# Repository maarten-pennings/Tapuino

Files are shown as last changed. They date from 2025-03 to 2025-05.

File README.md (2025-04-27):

# Tapuino

My take on the famous Tapuino; "The $20 C64 Tape Emulator". 
Below we see the PCB, the assembled PCB, the encased PCB, and again next to the datasette.

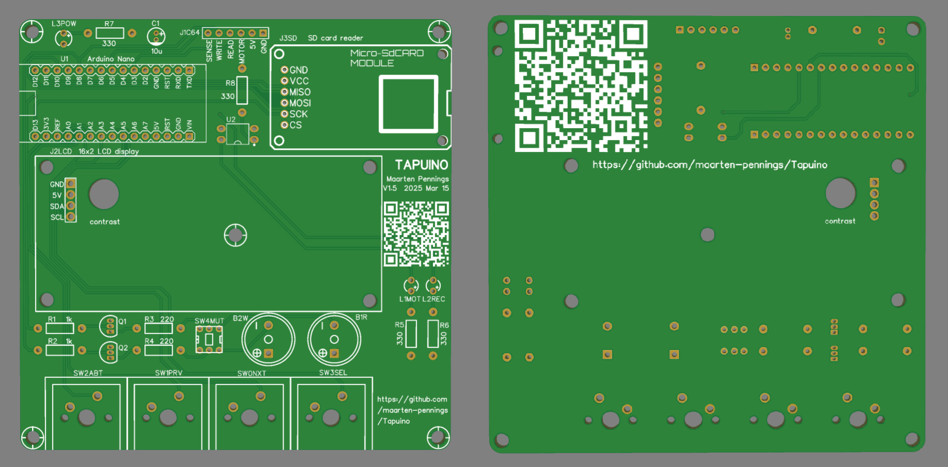
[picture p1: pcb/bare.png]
Tapuino PCB


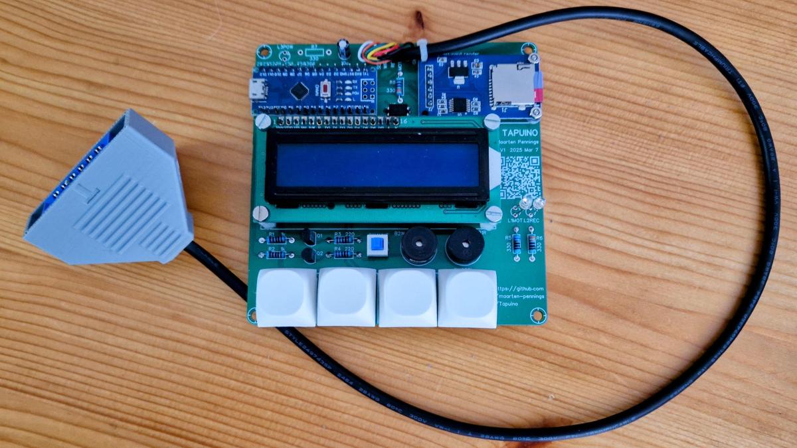
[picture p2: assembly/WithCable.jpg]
Tapuino assembled


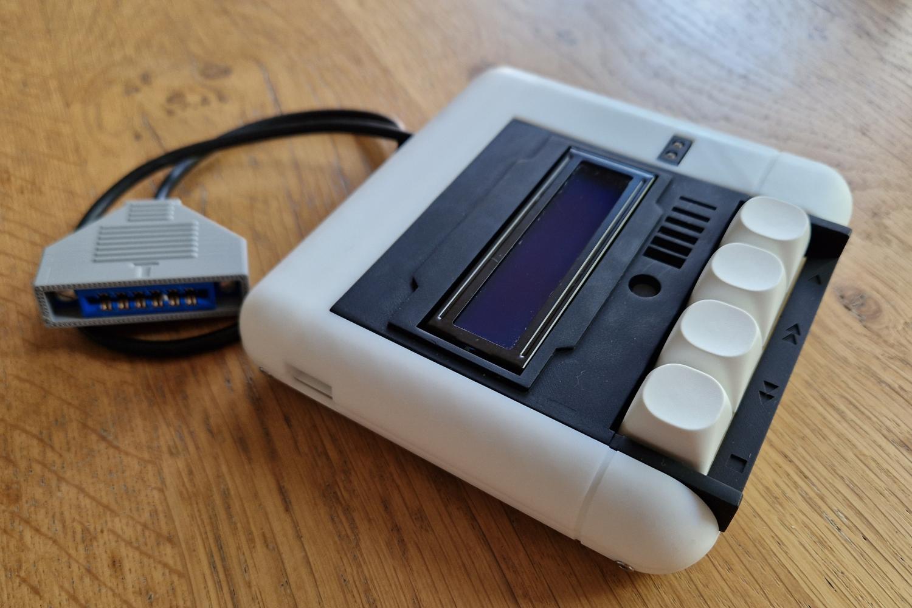
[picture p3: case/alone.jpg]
Tapuino alone


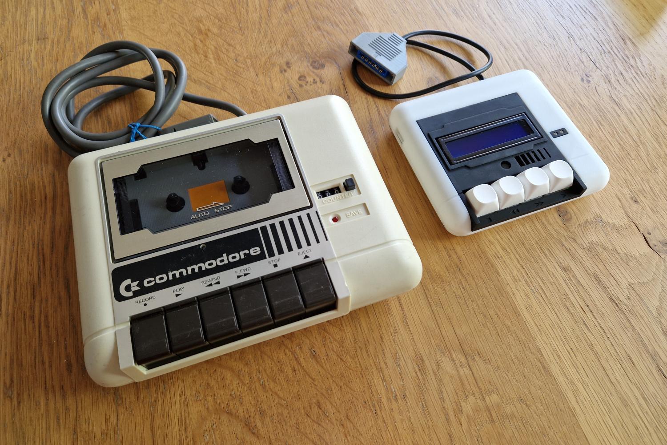
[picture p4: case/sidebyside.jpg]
Tapuino side by side with datasette


## Introduction

This project is a clone of [Tapuino ](https://github.com/sweetlilmre/tapuino) by "sweetlilmre" (Peter Edwards).

In a nutshell: Tapuino is an Arduino Nano, that together with an SD card reader and a 
simple user interface (LCD screen and 4 buttons) implements a sound recorder/player. 
The SD card stores Commodore 64 software in the form of 
[TAP](http://unusedino.de/ec64/technical/formats/tap.html) files; I think of them as 
WAV files; the bleeps encode the software. Tapuino plugs into the (6-pin) cassette 
port of the C64, which also supplies 5V to Tapuino.

The UI on the Tapuino lets you browse through the (directories on the) SD card, selecting a TAP file.
When the user types `LOAD` on the C64, the C64 switches on the MOTOR pin on the cassette 
port, the Arduino sees that and starts playing the TAP file on the READ pin of the 
cassette port. To make the retro experience complete, I added a speaker so that I can hear the bleeps.

It is also possible to type `SAVE` on the C64. In this case the Arduino takes the signal
from the WRITE pin on the cassette port and converts that to a TAP file in a fixed
directory of the SD card. One bummer: the user typically types `SAVE "name"`, but since
the name comes in as bleeps on the WRITE pin, this name is not accessible to the Arduino. 
The user has to enter a name for the file on the SD card, using the Tapuino GUI (slow) or accept 
auto-naming (basically a sequence number). Of course the bleep-encoded file name is still
part of the TAP file, so it is reported back to the C64 upon a `LOAD`.

I do not know if it is a bummer or not, but Tapuino emulates a datasette on the audio level.
This means it also has the speed of the original datasette. Quoting 
[stack exchange](https://retrocomputing.stackexchange.com/questions/16700/did-computer-games-for-commodore-64-really-take-25-minutes-to-load-if-everyth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,minutes%20to%20load%2048%20kilobytes)
"tape data rate is calculated at 55 bytes per second, giving approximately 15 minutes to load 48 kilobytes".
It is however possible to use cassette speed loaders (there is one in this repo as [TAP](tapes) file).

A quick computation: the C64 has 64k of RAM, but most tape games will be smaller than that.
On a 4 GB SD card (Arduino probably handles up to 32 GB) that would mean 4G/64k or 65536 
TAP files. Sounds plenty enough, but be warned the [Tape Archive](https://archive.org/details/Ultimate_Tape_Archive_V4.5) is nearly 20 GB zipped.

## PCB

One problem that I had is that I could not find a complete schematic. 
Peter Edwards' has Fritzing schematics and Vero board drawings, but no real schematics.

For example, the Control 0 and Control 1 lines are still a bit of a mystery.
Also, very hidden, there appears to be a GPIO pin that signals recording as opposed to playing. 

In the end, I did design my own [PCB](pcb).
It's also fun.

Instead of using cheap switches, I decided to go for Cherry MX switches.
Nice and big, looking a bit similar to the big switches on the actual datasette.

## Assembly

I hand assembled the PCB. See result in the [assembly](assembly) directory.
There were some errors in the V1 PCB that had to be patched; see [pcb section](pcb#errors).

## Software

> **Warning** Peter Edwards writes on his GitHub: This project is now in maintenance mode and has been superseded by the Tapuino Next.

And indeed, there are multiple dangling links, for example to Peter's video, and to his blog. 
I did find a [2014 blog](https://sweetlilmre.blogspot.com/2014/07/tapuino-20-c64-tape-emulator.html)

Due to all dangling links, I was afraid the Tapuino [sources](https://github.com/sweetlilmre/tapuino) might disappear. 
I decided to clone the [firmware](firmware), and I made some changes.
The biggest change is character prediction when editing (SAVE) filenames.
I did a bit of statistical counting, see [charcount](charcount).
The first checkin in my repo is the original - without my changes.

## Case

I did design a "sleeve" for the connector, and a 3-part shell for the itself.
The connector was printed at home with a filament printer, the 3-part shell at JLCPCB using SLA printer.
See [case](case).

## Cost

Overall cost is 35 euros. The most expensive part is the casing; without that the Tapuino 
costs just over 15 euros. See [costs](costs).

(end)

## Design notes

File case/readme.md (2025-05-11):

# Tapuino case

This directory contains the 3D printing files.

## Sleeve

I bought a 2x6 pins [PCB connector](https://www.aliexpress.com/item/33015746310.html).
I designed a sleeve for that, that is supposed to look a bit like the original:

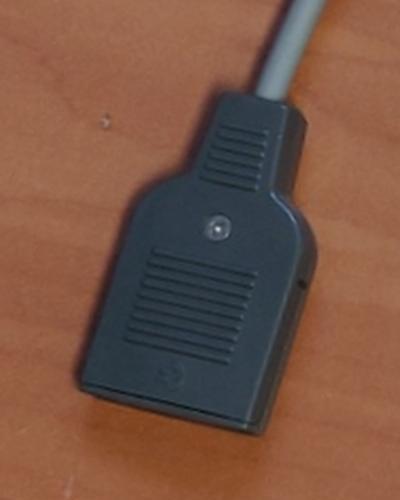
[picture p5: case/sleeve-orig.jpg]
original


This is my version.
The [stl](sleeve-square.stl) is in the repo.

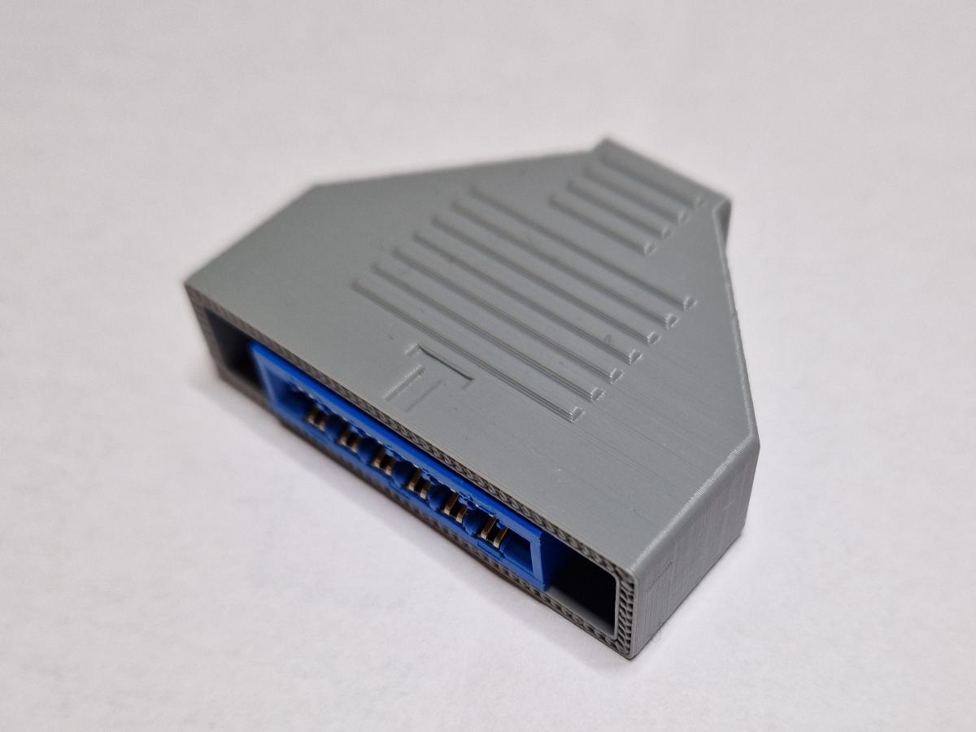
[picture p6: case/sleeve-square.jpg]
mine front
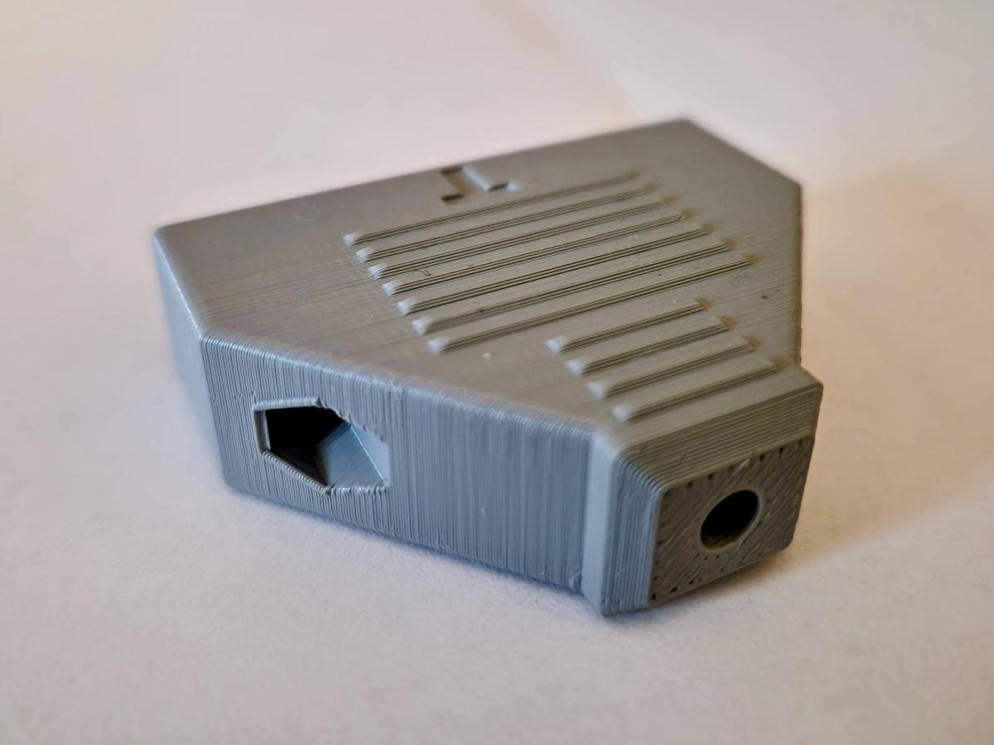
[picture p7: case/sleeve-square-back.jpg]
mine back
  

## Tapuino case V1

I also made a casing for the Tapuino itself.
I wanted it to look like the original datasette.

This is the result of a couple of evenings with Fusion 360.

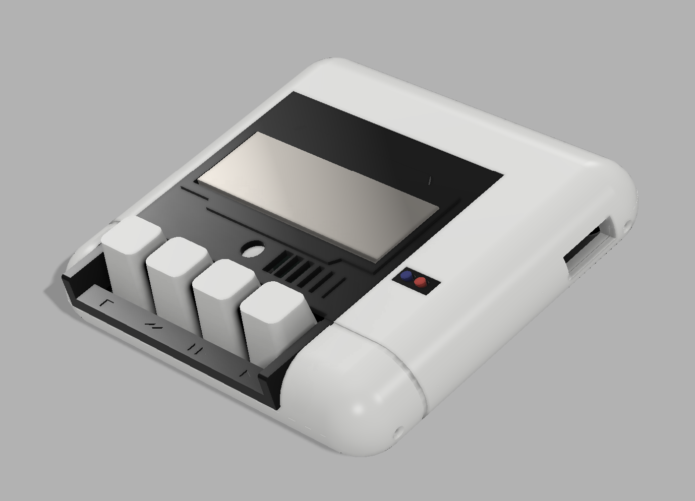
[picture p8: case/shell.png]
shell


It consists of a bottom half ([STL](ShellBot.stl)) and a top half ([STL](ShellTop.stl)) and the top half has a black inlay ([STL](Inlay.stl)).

I made prototypes with my 3D printer, but then ordered at [JLCPCB](https://jlcpcb.com/DMP).
I did go for low(est) cost in material and shipping: €17.30.

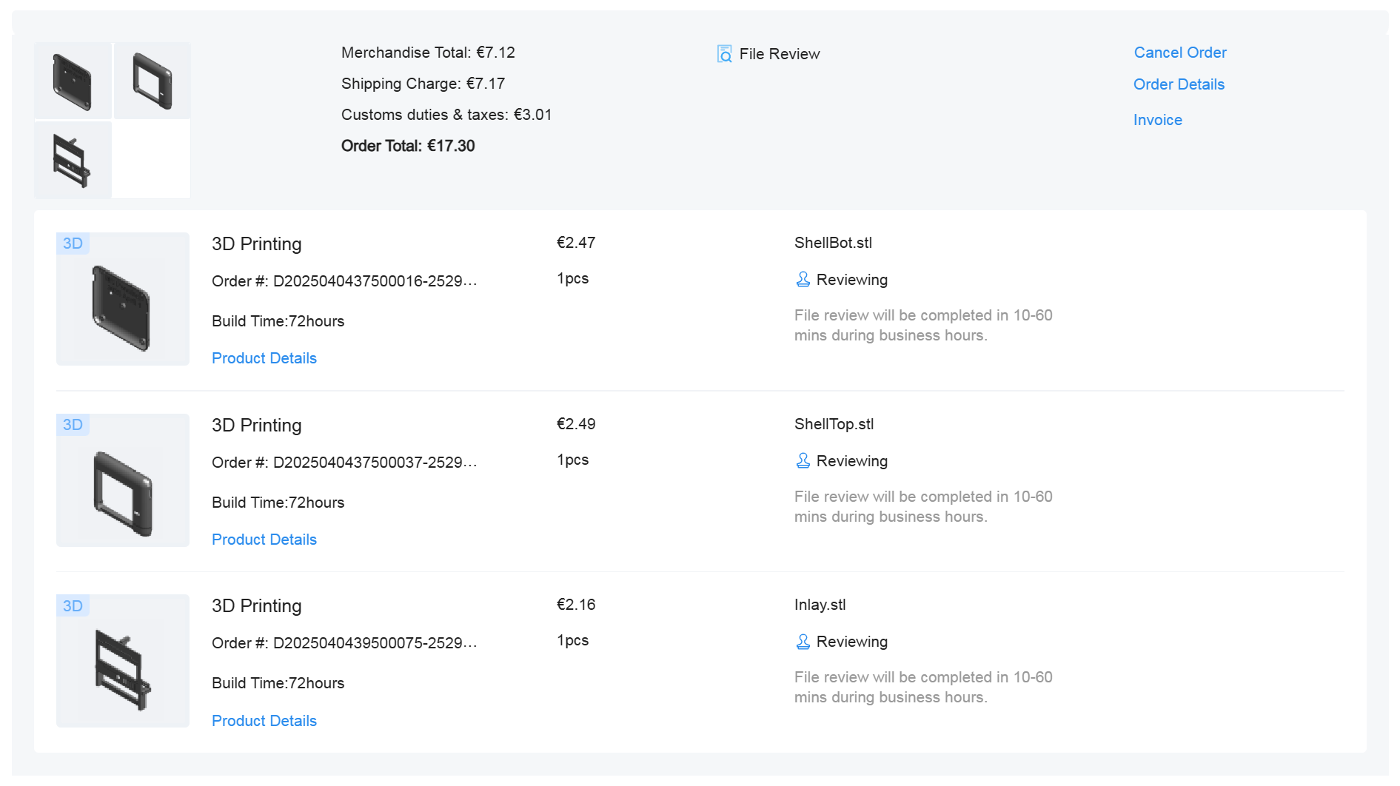
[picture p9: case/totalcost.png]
total cost


Unfortunately, I got a mail from JLCPCB:

> Due to the geometry of this workpiece, there is a high risk of deformation.
> Usually, for flat parts, frame parts, enclosures with no strong ribs inside, and large unoccupied areas parts, long parts and the models could shrink to the center and warping to the diagonal lines and edges.
> Could you please confirm if the risks are acceptable for you?

## Tapuino case V2

I decided to follows JLCPCB's advise and add some ribs; to the bottom half ([STL](ShellBot2.stl)), the top half ([STL](ShellTop2.stl)), and even to the inlay ([STL](Inlay2.stl)),
and to resubmit my order.

Again, I did got for low(est) cost in material and shipping, but more plastic, €1.50 higher cost:

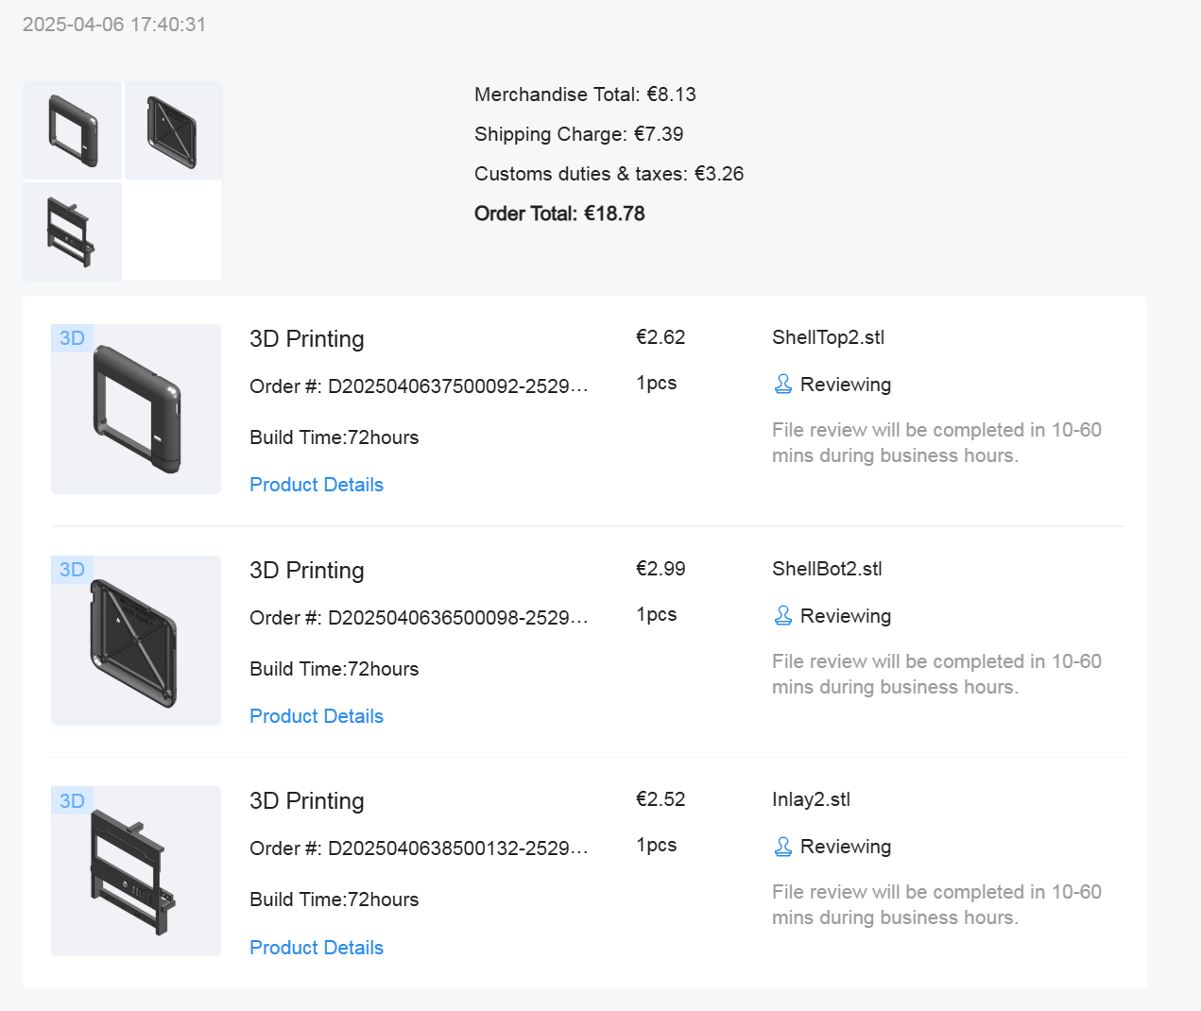
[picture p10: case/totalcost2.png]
total cost v2


## Result V2

Tapuino alone

Tapuino side by side with datasette

## Tapuino case V3

I friend wanted one, so I made some changes to V2.

- LCD gap a bit smaller.
- Lower the (new) ribs in the corner of the bottom, because it prevents the top to go completely down.
- Chamfer the edge of the bottom and top, because I liked the effect of the two halves not completely closing.
- Add an extra rib in the top, because there was a bit of warping in the print I got from JLCPCB.
- I made the chamfer for the heads of the screws that keep the two halves together a bit deeper.
- Now have hex gaps for nuts for the screws that keep the two halves together.
- Added to recessed panels at the top (for the counter and the save LED).
- Added version tags in all three prints.

Here are the (renders of the parts), the bottom half ([STL](ShellBot3.stl)), the top half ([STL](ShellTop3.stl)), and the inlay ([STL](Inlay3.stl)).

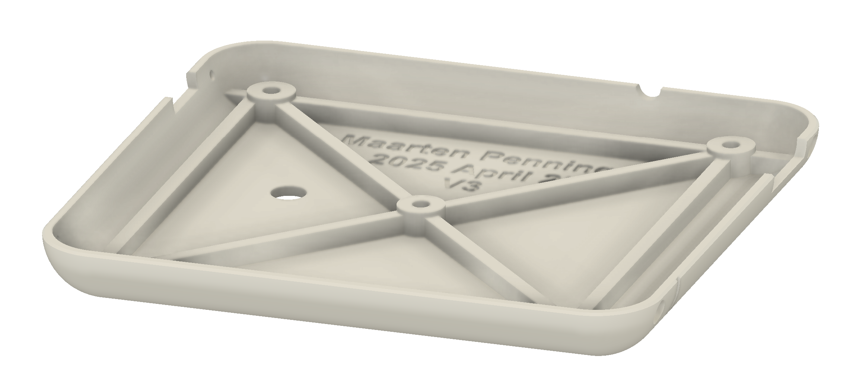
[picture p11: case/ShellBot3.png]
Bottom half V3


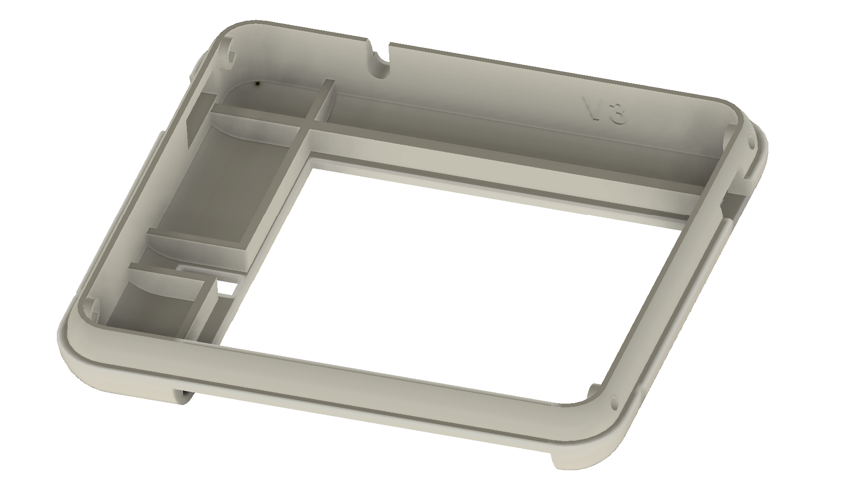
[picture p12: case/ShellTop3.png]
Top half V3


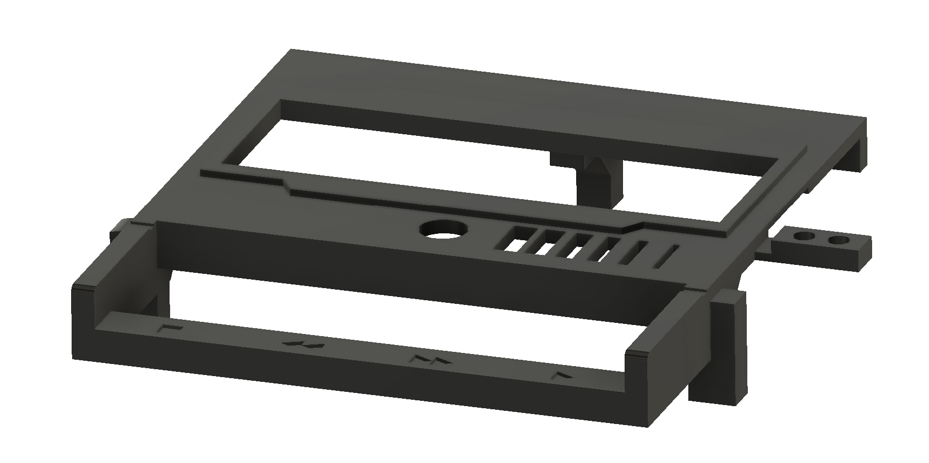
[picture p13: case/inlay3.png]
Inlay V3


This is the render of the assembly.

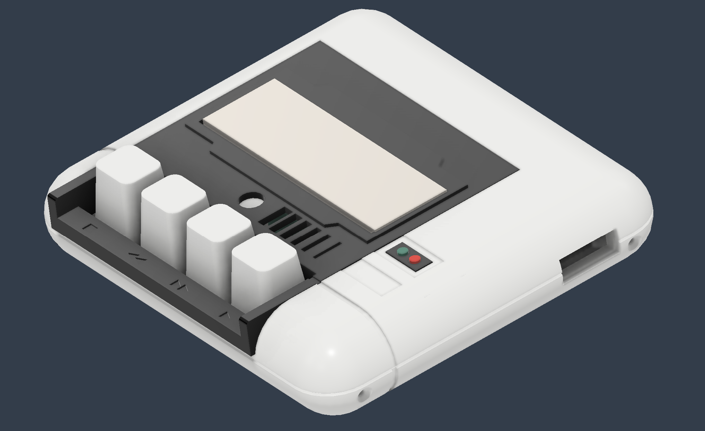
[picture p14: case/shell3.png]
Shell V3


(end)

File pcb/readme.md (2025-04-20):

# Tapuino PCB

In this directory you find my design of the PCB for the Tapuino.

## Schematics

I made the schematics in [EasyEda](https://easyeda.com).
Files are stored in their cloud, but you can also download the [source](Tapuino-sch-v1.5.json).
Not sure how many other tools can process those files.
To be sure, I also exported a [pdf](Tapuino-sch-v1.5.pdf).

Note that I have two sound "channels" one for recording and one for playback.
That is a big overkill, but I didn't want to complicate the schematics
by having two inputs (READ and WRITE pin) to one speaker. It adds a bit of PCB area.
Cost-wise it is not much of a problem, the entire two-channel solution costs less 
than 50 cent (35 for the two buzzers, 6 for the mute button and some cents for the
resistors and transistors). If you don't want sound, you can skip this part of the
schematics.

## Errors

I made a couple of errors in the V1 design that are fixed in the V1.5 design
- SCL/SDA were swapped on the Arduino Nano.
  This was patched by replacing two pins in the pin header of the LCD by wires and crossing those.
- Pins 1/2 and 3/4 were swapped on the optocoupler (U2).
  This was patched by placing the optocoupler upside down (bending all pins 180 degrees).
- Green LED (L1MOT) was too bright.
  Changed R5 from 330 Ω to 680 Ω.

## Layout

Next step is layout, also done in EasyEda. Also here the [source](Tapuino-pcb-v1.5.json) downloaded from the cloud.
And the pdf's, not sure how useful that is, one with [top](Tapuino-pcb-v1.5-top.pdf) view and one with [bottom](Tapuino-pcb-v1.5-bot.pdf) view.

I tried to follow the layout of the original datasette: big buttons at the front;
the tape (LCD) in the center; tape counter (2 LEDs) on the center right; nothing at the back 
except the cable to the C64.

bare

QR code to this repo for on the PCB.

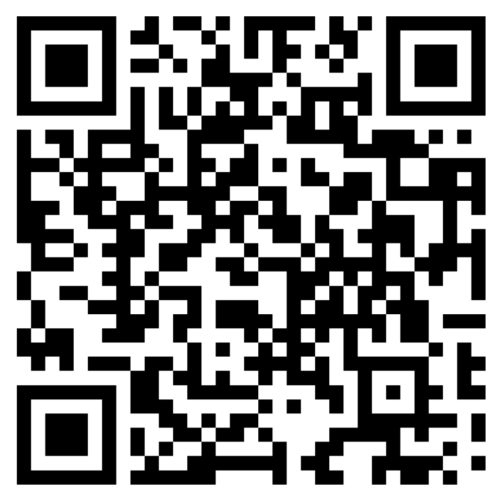
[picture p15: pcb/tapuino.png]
tapuino QR


I made a couple of changes in the v1.5 Layout
- Moved the right-side holes of the SD card PCB a bit to the left
- Moved the contrast hole up.

## Renders

Those fabulous colleague makers using EasyEda, create wonderful "models".
I needed three: for the Arduino Nano, for the SD card reader, and for the LCD screen.
I found all of them, with full details and colors.
So I have pretty good looking renders of my PCB:

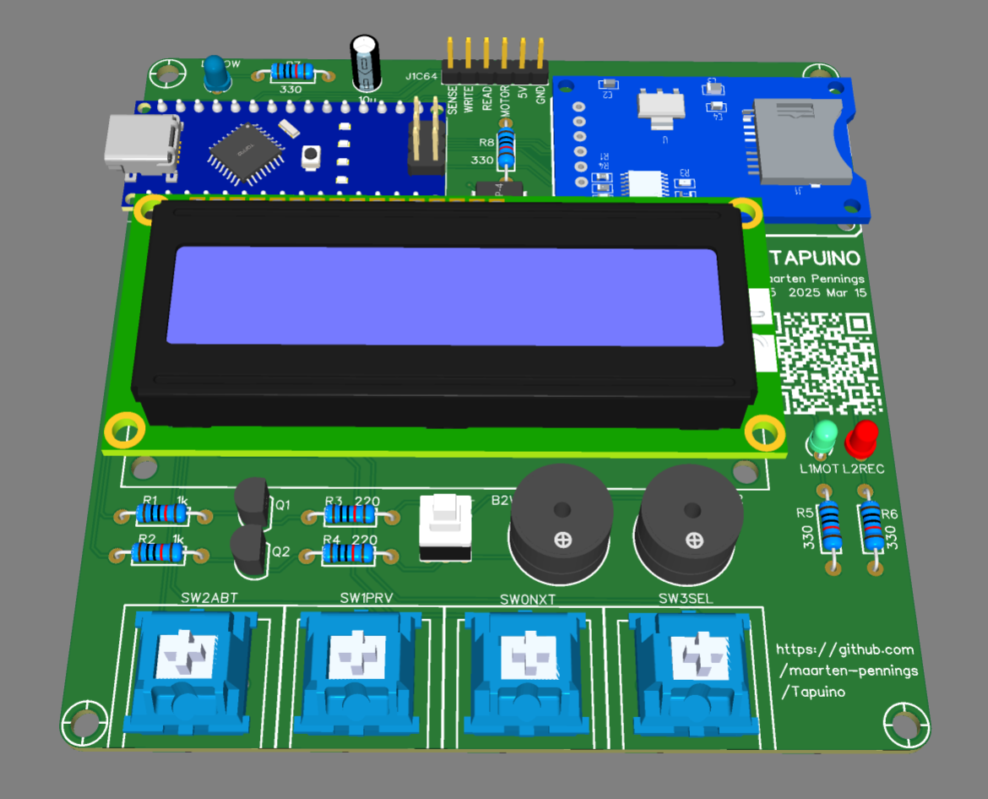
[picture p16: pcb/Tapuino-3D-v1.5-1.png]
render 1


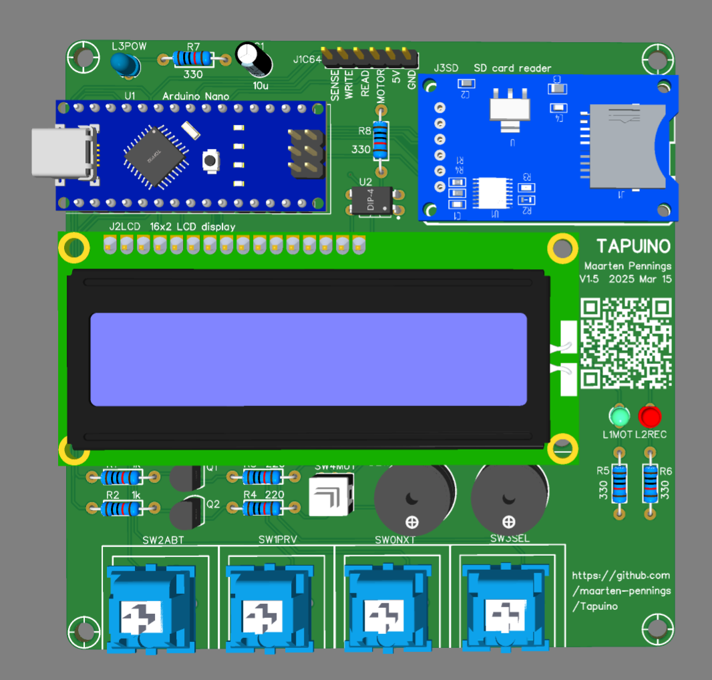
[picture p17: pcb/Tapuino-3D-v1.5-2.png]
render 2


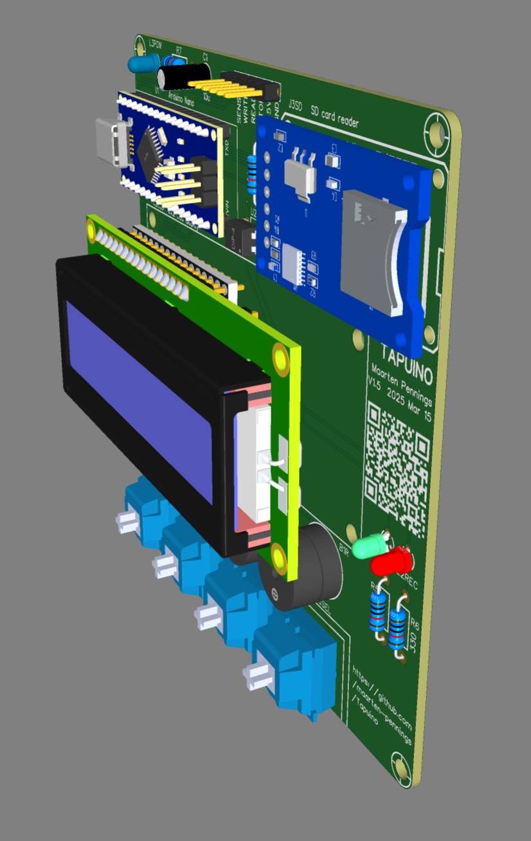
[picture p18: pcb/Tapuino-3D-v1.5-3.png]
render 3


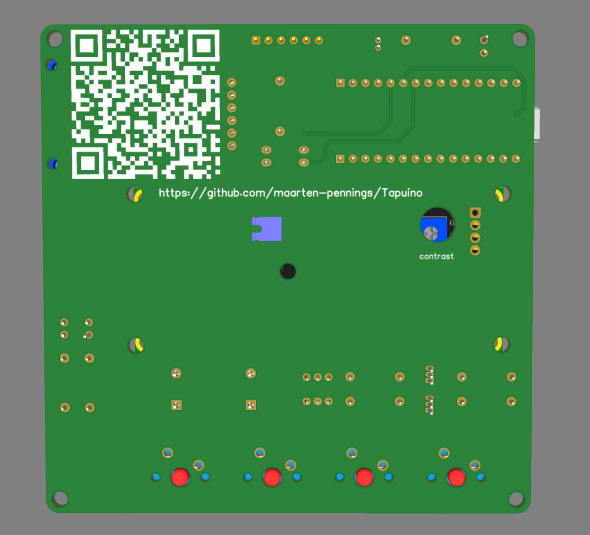
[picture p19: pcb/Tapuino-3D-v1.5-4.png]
render 4


## PCB Manufacturing

The final [gerber](Tapuino-gerber-v1.5.zip) was sent to [JLCPCB](https://jlcpcb.com/DMP).
Manufacturing in 2 days for €1.85 for 5 PCBs. There was 15-day shipping for €1.63, but I opted for
a faster one €6.94.

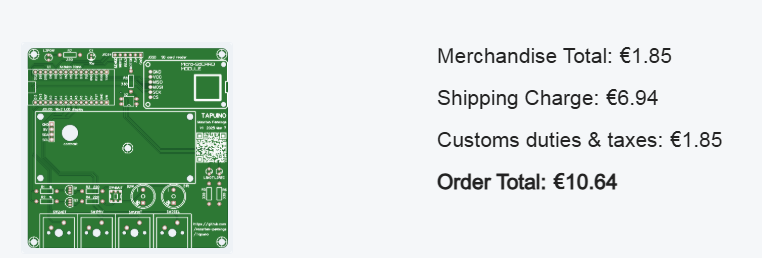
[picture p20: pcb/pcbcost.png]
PCB cost


I ordered on Friday, they arrived at my house (The Netherlands) the next Thursday - four working days.

(end)

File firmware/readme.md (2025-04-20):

# Tapuino firmware

Some notes on the Tapuino firmware.

## My findings

- The UI also has a COMMAND_SELECT_LONG and COMMAND_ABORT_LONG.
  They are especially relevant in manual filename entry (for SAVE)
  
  - Short SELECT means start editing next character.
  - Long SELECT means select character, stop entering characters, start recording the file.
  - Short ABORT means go back to editing previous character.
  - Long ABORT means stop entering file name.

- Lowercase `m` on the LCD means waiting for motor power by C64.
  Uppercase `M` means C64 powers the motor.
  
- The main menu also has "options" configuration.

## My changes

- I changed all sources to have uniform line endings.

- I added my configuration in [config-user.h](config-user.h).

- Suppressed a [warning ](https://github.com/maarten-pennings/Tapuino/blob/main/firmware/tapuino/ccsbcs_avr.c#L9).

- Fixed some typos (eg [Ether](https://github.com/maarten-pennings/Tapuino/blob/main/firmware/tapuino/config.h#L9)).

- In the "file browser" shown with "play" I filtered out also _hidden_ and _system_ files.
  See [source](https://github.com/maarten-pennings/Tapuino/blob/main/firmware/tapuino/fileutils.c#L8).
  The "system" was needed because windows creates a some funny system directory each time I plug in the SD card in my system.
  I added  "hidden" because this allows me to add some files (documentation, images) that I do not want to pop up in the Tapuino browser.

- Replaced hard-coded sizes with expression (eg [`sizeof(ppitems)/sizeof(ppitems[0])`](https://github.com/maarten-pennings/Tapuino/blob/main/firmware/tapuino/menu.c#L272)
  and line [373](https://github.com/maarten-pennings/Tapuino/blob/main/firmware/tapuino/menu.c#L373), and 
  [463](https://github.com/maarten-pennings/Tapuino/blob/main/firmware/tapuino/menu.c#L463)).

- I was confused by `TAPE_READ_LOW` which sometimes referred to a LED. Changed that to [signal](https://github.com/maarten-pennings/Tapuino/blob/main/firmware/tapuino/tapuino.c#L453).

- I bumped the version from 2.10.0 to 2.11.0.

- Added character prediction to manual [file name entry](https://github.com/maarten-pennings/Tapuino/blob/main/firmware/tapuino/menu.c#L178).
  See also [next char](https://github.com/maarten-pennings/Tapuino/blob/main/firmware/tapuino/memstrings-neutral.c#L7) definition.
  
- I bumped the version from 2.11.0 to 2.12.0.

- Changed startup message from `INIT... V: 2.12.0` to `Tapuino 2.12.0`

- I bumped the version from 2.11.0 to 2.13.0.

## Uploading

Upload failed at first. Forgot my Nano has an "old" bootloader.

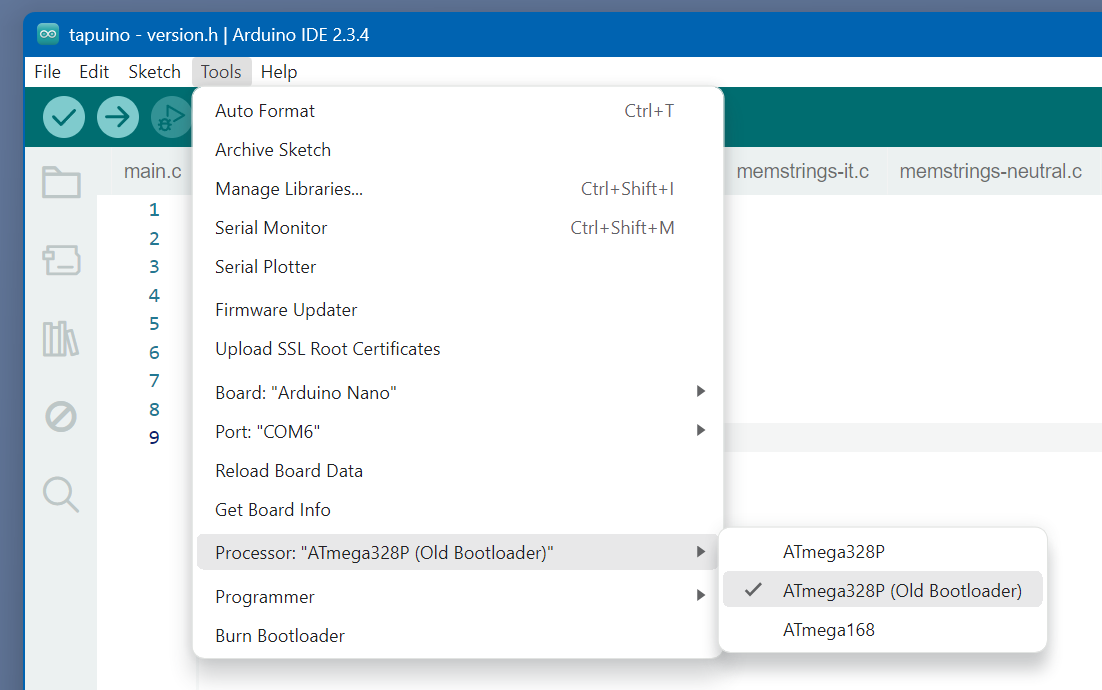
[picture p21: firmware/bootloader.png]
bootloader


Memory usage is relatively low

```
Sketch uses 26868 bytes (87%) of program storage space. Maximum is 30720 bytes.
Global variables use 1608 bytes (78%) of dynamic memory, leaving 440 bytes for local variables. Maximum is 2048 bytes.
```

In 2.12/13

```
Sketch uses 26990 bytes (87%) of program storage space. Maximum is 30720 bytes.
Global variables use 1608 bytes (78%) of dynamic memory, leaving 440 bytes for local variables. Maximum is 2048 bytes.
```

(end)

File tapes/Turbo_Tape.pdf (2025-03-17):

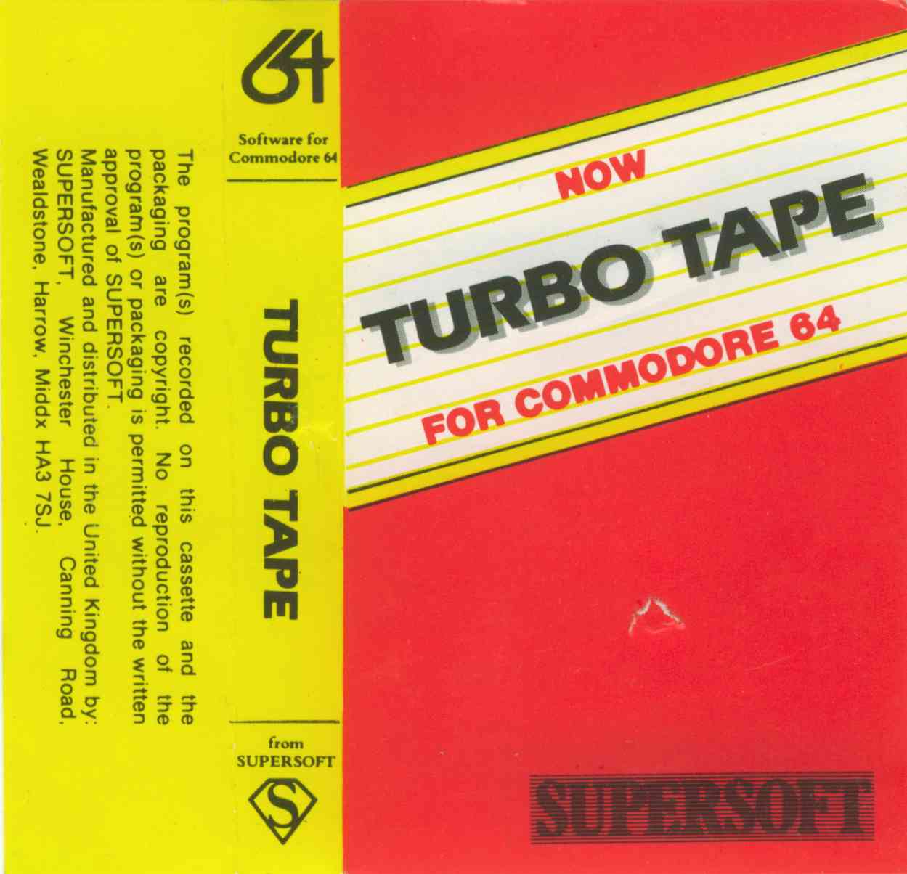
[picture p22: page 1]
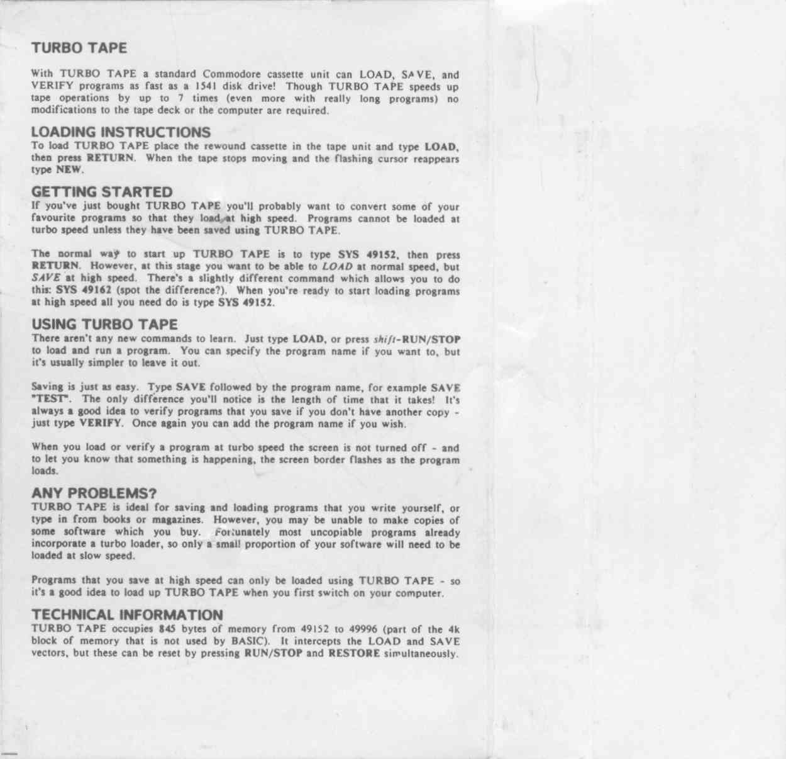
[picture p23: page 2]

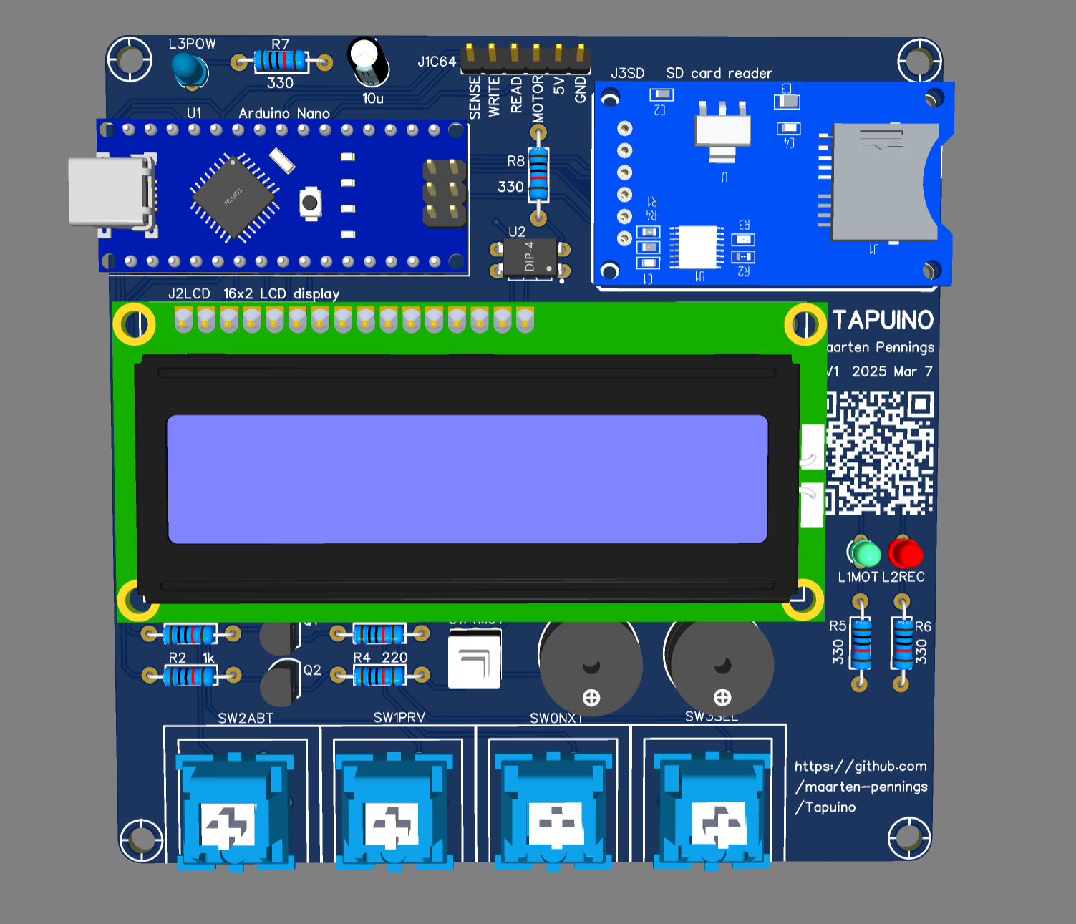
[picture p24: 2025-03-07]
pcb/Tapuino-3D-v1-2.png

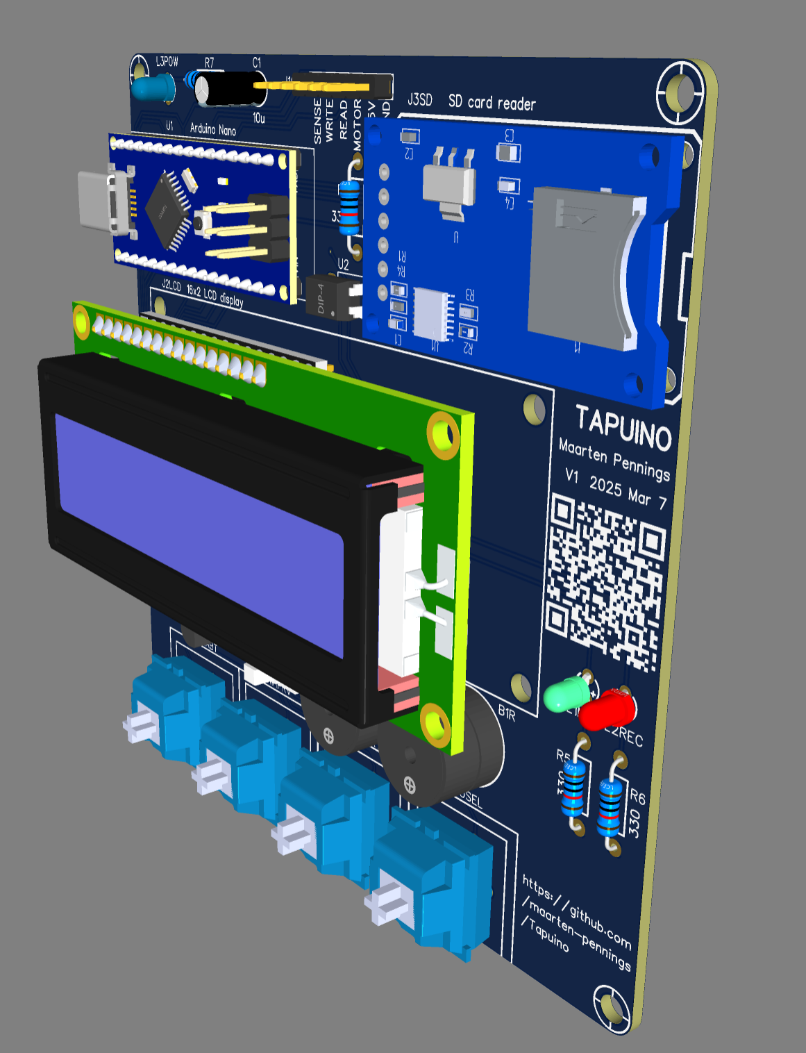
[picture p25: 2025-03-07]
pcb/Tapuino-3D-v1-3.png

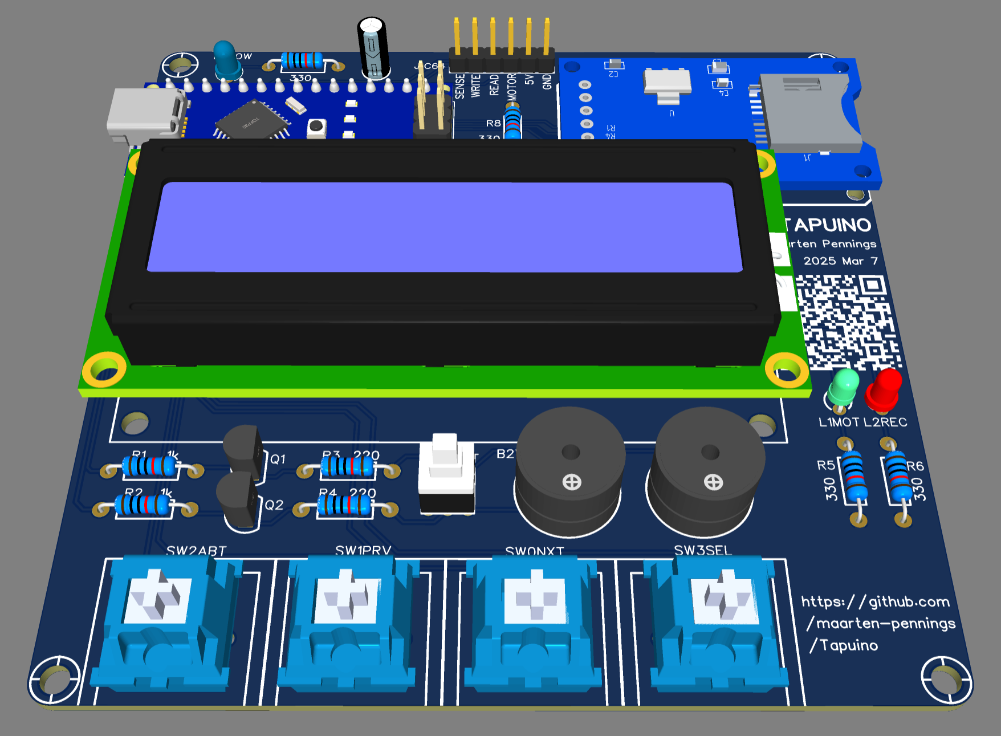
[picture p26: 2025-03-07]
pcb/Tapuino-3D-v1-1.png

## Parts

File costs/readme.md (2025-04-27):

# Tapuino costs

This file gives an indication of the costs for making a Tapuino.

## Components

- [Arduino Nano](https://www.aliexpress.com/item/4000310677263.html)
  with micro USB (maybe I should have gotten USB C). 1 for €2.94.

- [Edge connector](https://www.aliexpress.com/item/33015746310.html);
  3 for €1.96.

- [16x2 LCD with I2C adapter](https://www.aliexpress.com/item/1005006964073869.html).
  I took the blue one. 1 for €2.62.

- [SD card reader module](https://www.aliexpress.com/item/1005006457603056.html)
  with 3v3 LDO and level shifters. 1 for €1.08.

- [BC547 transistor](https://www.aliexpress.com/item/1005007339082012.html);
  100 for €1.33.

- [LEDs in blue, green, red](https://www.aliexpress.com/item/1005005708510866.html);
  100 for €1.83.
  
- [Passive Buzzer](https://www.aliexpress.com/item/1005007548587680.html)
  ("passive" means it is like a speaker driven by AC, "active" means
  it contains an oscillator driven at DC and it makes one fixed beep tone).
  10 pieces for €1.76.

- [Clicky blue Cherry MX switches](https://www.aliexpress.com/item/1005007052759423.html)
  30 for €3.63. I hope they are 1 unit wide (0.75 inch or 19.05mm).

- [Key caps](https://www.aliexpress.com/item/1005006477890497.html)
  for the Cherry MX switches. 30 pieces for €10.94.

- [Mute button](https://www.aliexpress.com/item/32699676258.html).
  I used the "self locking" (blue) with 2mm pitch.
  It is a double pole, double throw; 40 switches for €2.49.

- [Resistors](https://www.aliexpress.com/item/1005008240285872.html);
  1280 for €7.09.

- [Opto coupler](https://www.aliexpress.com/item/1005006281381268.html);
  20 for €1.09.

- [capacitors](https://www.aliexpress.com/item/1005007426523574.html);
  120 for €2.66.

## Cost

The table below lists the cost.
Be aware that this table is overly positive; it does not include shipping
for the bulk goods and it assumes the overshoot parts are useful for another project.

| Name | Designator | Quantity  |  Price  |
|:---|:---|:---:|---:|
| Arduino nano | U1 | 1 | €  2.94 |
| Edge connector to C64 | J1C64 | 1 | €  0.65 |
| LCD module | J2LCD | 1 | €  2.62 |
| Micro SD Card-module  | J3SD | 1 | €  1.08 |
| BC547B | Q1,Q2 | 2  [0] | €  0.03 |
| LED 3mm | L1MOT, L2REC, L3POW | 3  [0] | €  0.05 |
| Passive buzzer | B1R,B2W | 2  [0] | €  0.35 |
| Cherry MX keys | SW0NXT,SW1PRV,SW2ABT,SW3SEL | 4 | €  0.48 |
| Key caps | SW0NXT,SW1PRV,SW2ABT,SW3SEL | 4  [0] | €  1.46 |
| Switch DPDT | SW4MUT | 1  [0] | €  0.06 |
| Resistor 330Ω | R5,R6,R7,R8 | 4  [1] | €  0.02 |
| Opto coupler PC817C | U2 | 1 | €  0.05 |
| Resistor 1kΩ | R2,R1 | 2  [0] | €  0.01 |
| Resistor 220Ω | R3,R4 | 2  [0] | €  0.01 |
| 10u | C1 | 1 | €  0.02 |
| | | | |
| PCB | (5 piecs with shipping) | 1 | €  2.13 |
| Casing 3 parts | (with shipping) | 1 | € 18.78 |
| | | | |
| SD card | | 1 | €  2.28 |
| | | | |
| | | | € 33.02 |

The casing is by far the most expensive part, which you don't need. 
If you want to reduce more, you could consider removing all three LEDs, 
the buzzer and its driver circuit. But this is all cents range.
The biggest saving is replacing the cherry switches and caps 
with cheaper switches.
The optional PCB cost reductions are tagged with [ ] in the cost overview.

(end)

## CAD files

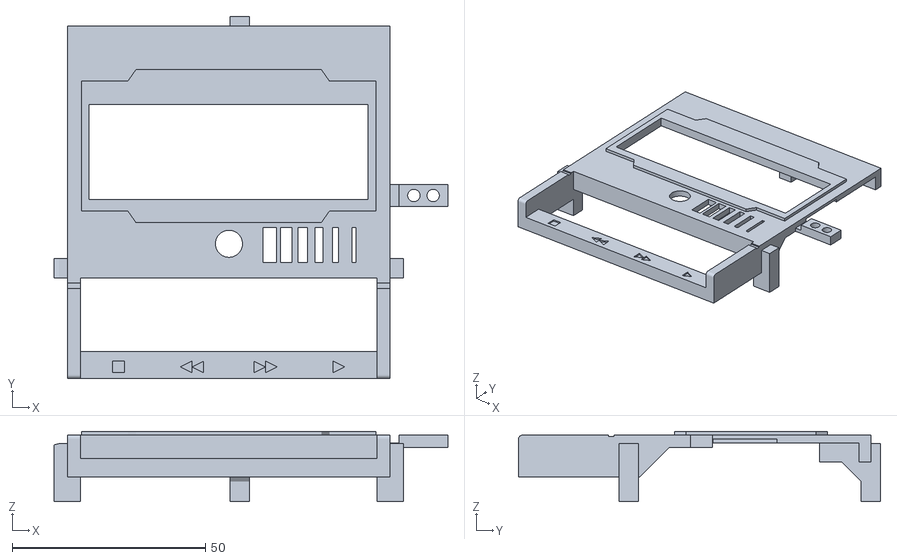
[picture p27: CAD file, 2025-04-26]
case/Inlay3.stl
101.8 x 93.6 x 18.2

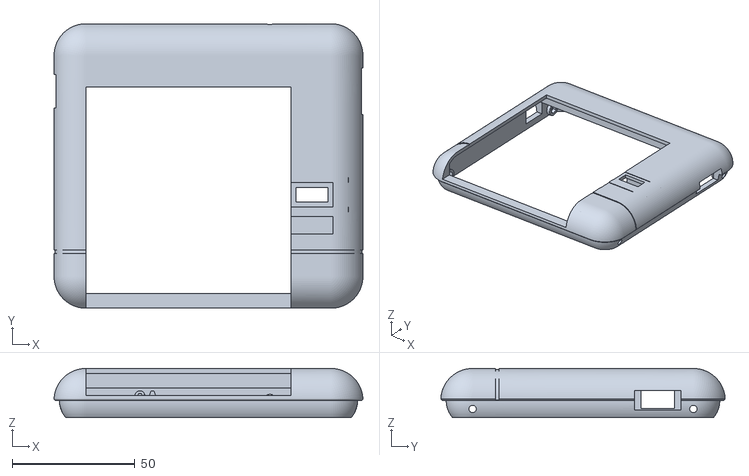
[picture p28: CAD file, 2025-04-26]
case/ShellTop3.stl
126.0 x 116.0 x 20.0

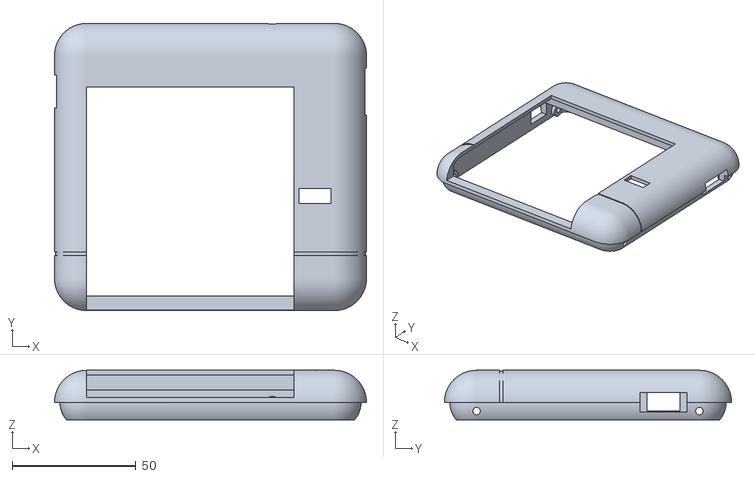
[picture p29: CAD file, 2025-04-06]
case/ShellTop2.stl
126.0 x 116.0 x 20.0

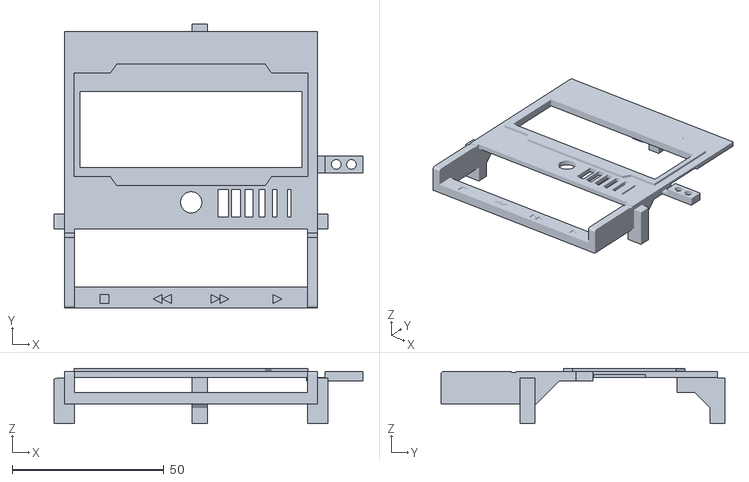
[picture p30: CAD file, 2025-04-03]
case/Inlay.stl
101.8 x 93.6 x 18.2

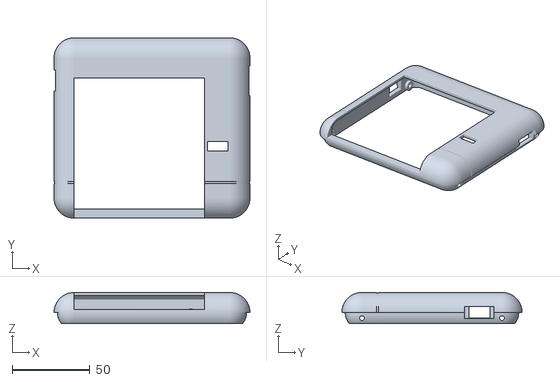
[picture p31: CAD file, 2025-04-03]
case/ShellTop.stl
126.0 x 116.0 x 20.0

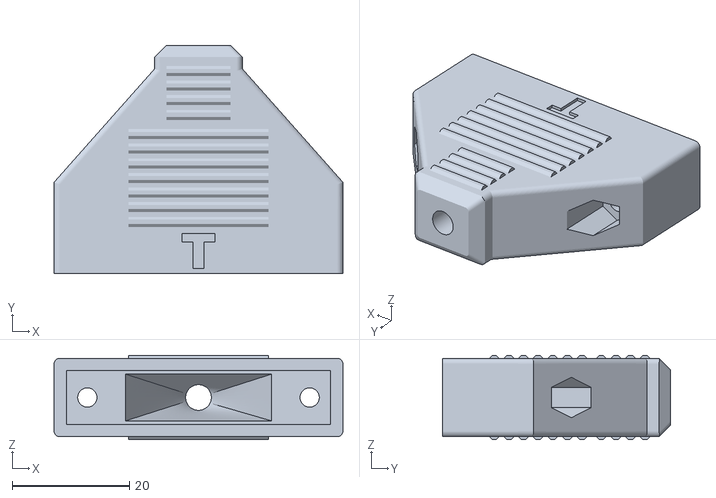
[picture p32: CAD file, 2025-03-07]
case/sleeve-square.stl
49.4 x 39.0 x 14.4

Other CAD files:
case/Inlay2.stl

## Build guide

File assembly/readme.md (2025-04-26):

# Assembly

In this directory you find my assembly results.

## Bare PCB

The 5 PCBs arrived after only 4 working days.
I ordered them without assembly, so that was my next step.

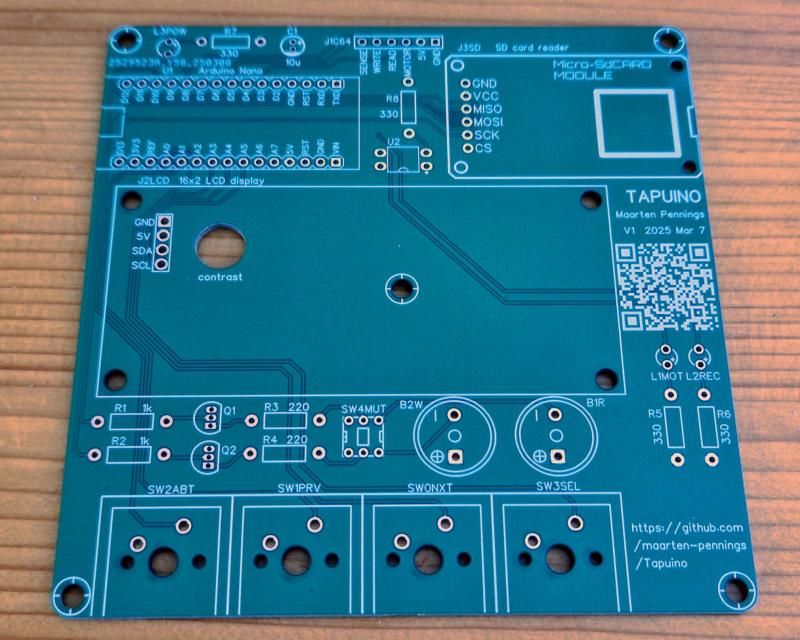
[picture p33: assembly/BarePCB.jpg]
Bare PCB


There are some [errors](https://github.com/maarten-pennings/Tapuino/tree/main/pcb#errors) in the V1.5 PCB.

These are the steps I followed for my second assembly.

- First, I flashed the Arduino Nano with a "blinky plus println".
  I'm glad I did this. The Nano did start, but it did not enumerate over USB.
  I discovered a capacitor was knocked off the board. When I mounted one back, all was fine.
  
  I flashed the Arduino Nano with the Tapuino [firmware](https://github.com/maarten-pennings/Tapuino/tree/main/firmware/tapuino).
  Unfortunately, it is hard to test on the bare board; I connected the LCD with clipwires 
  and saw `Init failed!`, which make sense because there is no SD board connected yet.

- I removed the power LED from the Nano.
  You do not need to do this, but the white casing is not opaque enough to block it, so I don't like it.

  I soldered the Nano, on pin headers, with the long side of the pins up.
  Otherwise they stick out at the bottom where there is not enough room, so a lot of clipping would then be needed.

- I soldered the LCD with SDA and SCL as wires instead of pin headers.
  This is needed because due to **PCB error**, they need to be crossed.

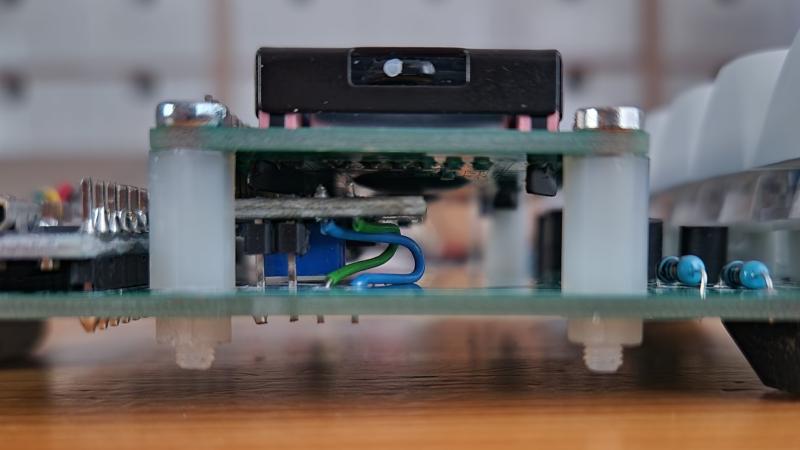
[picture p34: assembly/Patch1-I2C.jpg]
I2C swap
  
  
  I forgot, but I should have removed the red LED.
  Then I secured the LCD with standoffs 10mm. 
  
- Next I did the SD module. I first removed the existing pin header because I want the SD card slot at the top.
  Next I soldered the SD module on the PCB and secured it with on bolt, thick washer/spacer and a nut.

  Powering up the board now (with a working SD card inserted), no longer causes an error message on the LCD.
  
- The sound components needed to be placed before the keys (room wise),
  so the two buzzers, the mute button, four resistors and two transistors were placed next.
  
- I soldered the four cherry switches.

  Powering up the board in this stage, allow us to navigate the menu with the buttons.
  
- To test the sound, I needed to add the optocoupler, because via the optocoupler the "load" signal comes in.
  Here I needed to work around the second **PCB error**.
  The anodes and cathodes of the optocoupler are swapped; "fortunately" I did that twice, for the emitter as well as the detector.
  The second patch was to turn the optocoupler on its back, bending all 4 legs 180°.

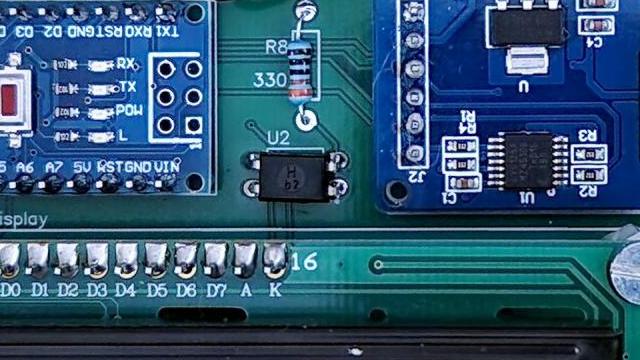
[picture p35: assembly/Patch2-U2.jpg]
U2 swap
  
  
  The pin 1 was is no longer at the lower right (where the marking dot is) but at the upper right (to wards R8).

  When you now power the board, and select a file to play, the Nano is waiting for 5V on MOTOR.
  By short circuiting the MOTOR and 5V on J1C64 playback should start: animation on the LCD and
  sound (remember to toggle the mute button - SW4MUT - if you don't hear beeps).

- Finally, I mounted the 10u cap, and the green (L1MOT) and red (L2REC) LEDs with their resistor (R5, R6).
  I did not mount the power LED (L3POW) with its resistor (R7).
  It is not really a **PCB error**, but I replaced R5 330Ω with 1000Ω, because it would be too bright.
  
  I repeated the play test from the previous step, now also the green LED switches on.

## With cable

The PCB seemed to work fine on USB, faking motor on by short circuiting the MOTOR and 5V on J1C64.

Next step was to add the cable with my own printed connector sleeve.

With cable

## Assembly completed

In the following photos you see the Tapuino in action.

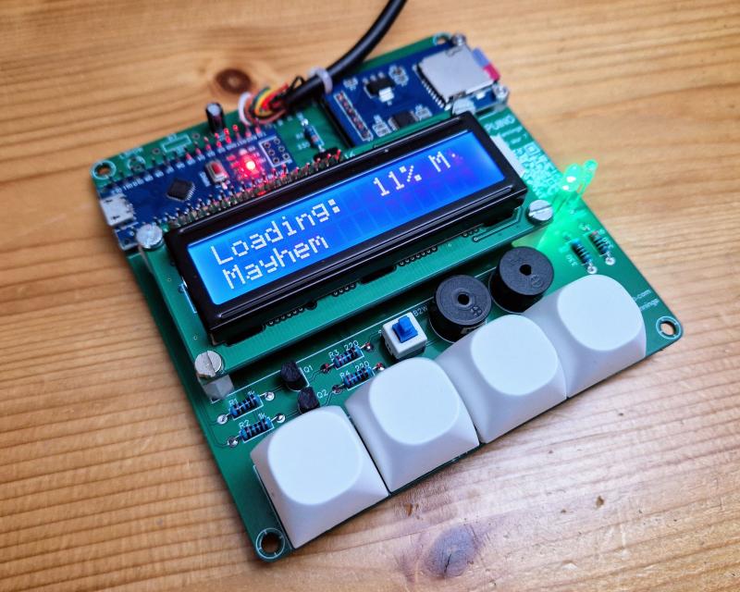
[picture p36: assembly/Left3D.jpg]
Left


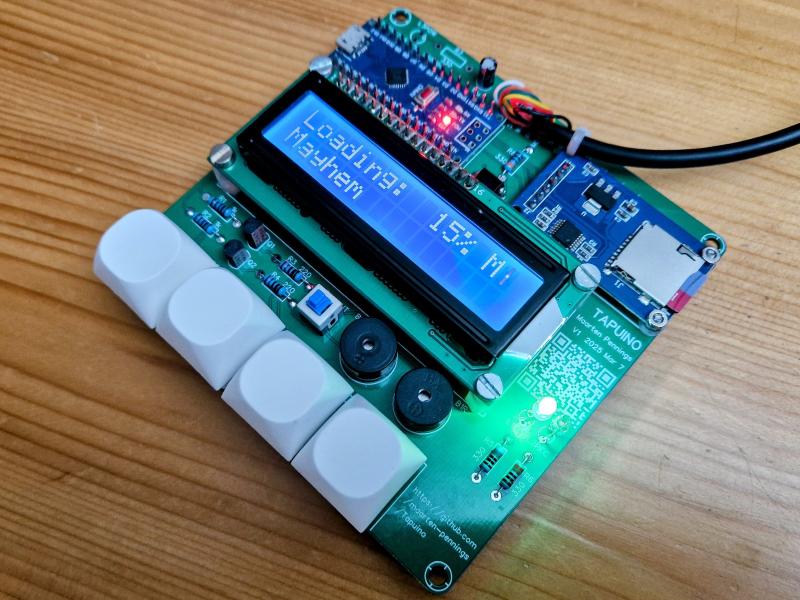
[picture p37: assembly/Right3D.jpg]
Right


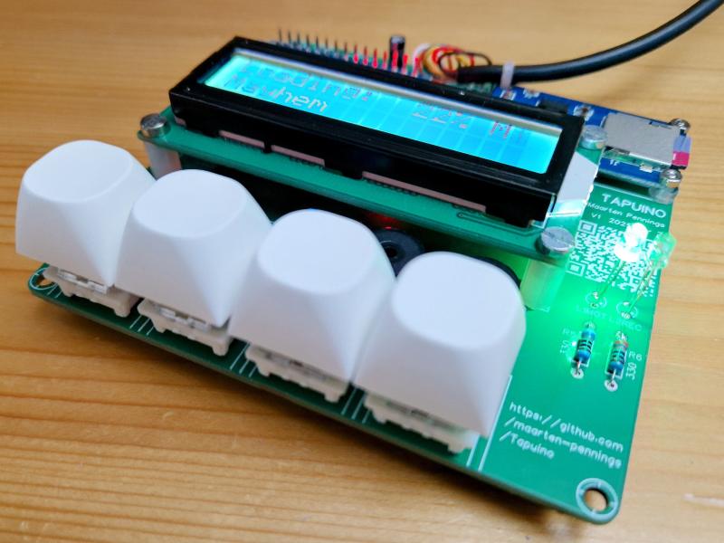
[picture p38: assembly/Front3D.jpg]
Front


(end)

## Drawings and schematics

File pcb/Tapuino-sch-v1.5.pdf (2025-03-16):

## LOAD and SAVE monitor

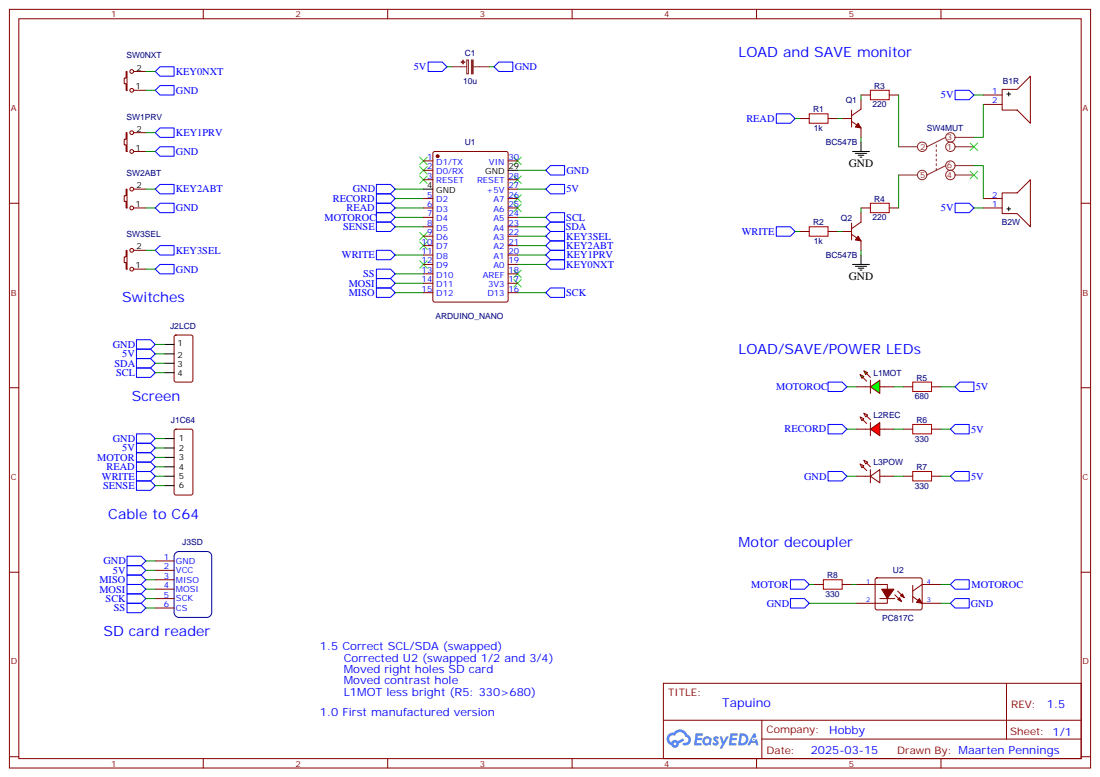
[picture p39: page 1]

LOAD/SAVE/POWER LEDs

1.5 Correct SCL/SDA (swapped)
Corrected U2 (swapped 1/2 and 3/4)
Moved right holes SD card
Moved contrast hole
L1MOT less bright (R5: 330>680)
1.0 First manufactured version

Drawn By: Maarten Pennings

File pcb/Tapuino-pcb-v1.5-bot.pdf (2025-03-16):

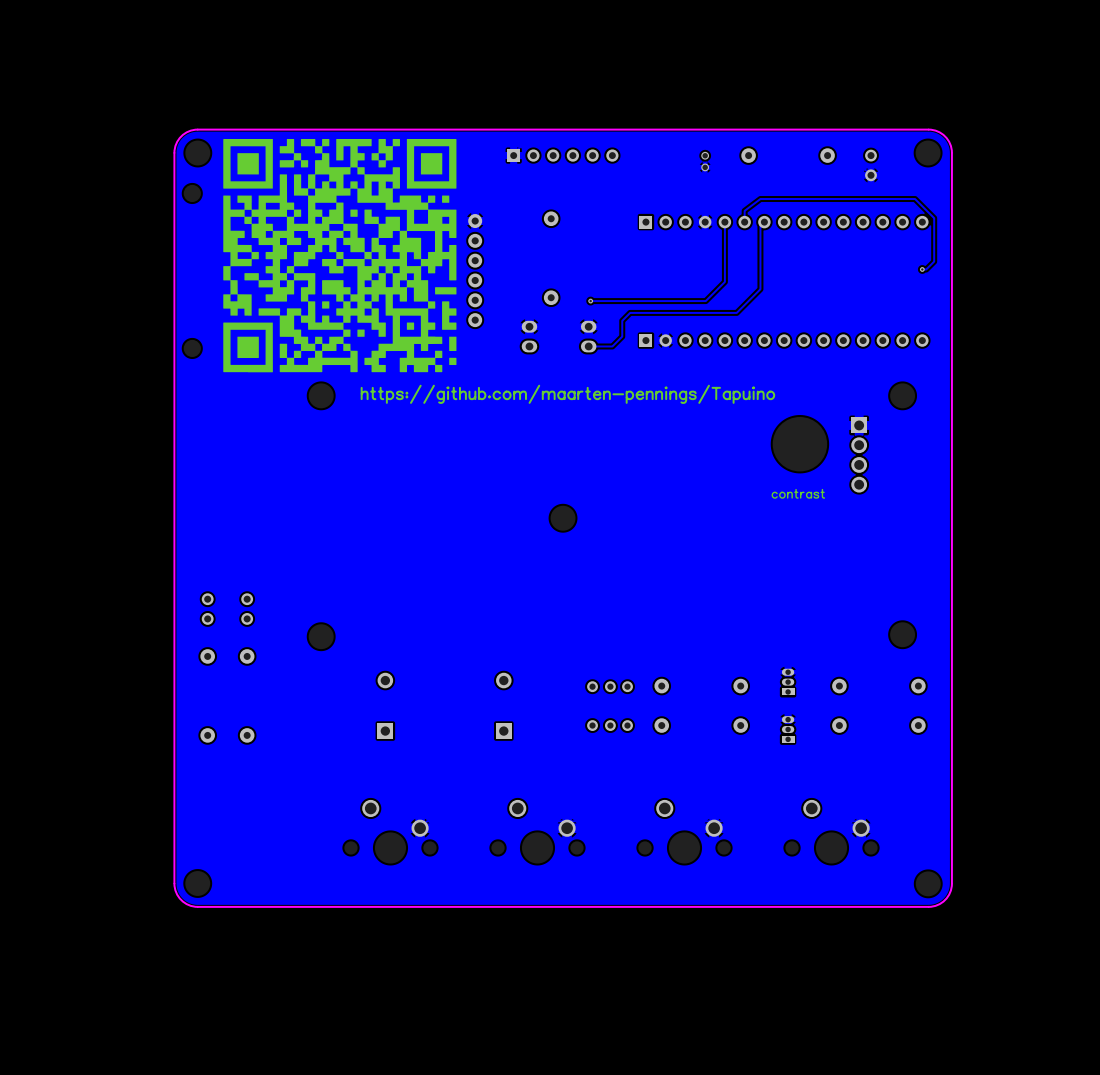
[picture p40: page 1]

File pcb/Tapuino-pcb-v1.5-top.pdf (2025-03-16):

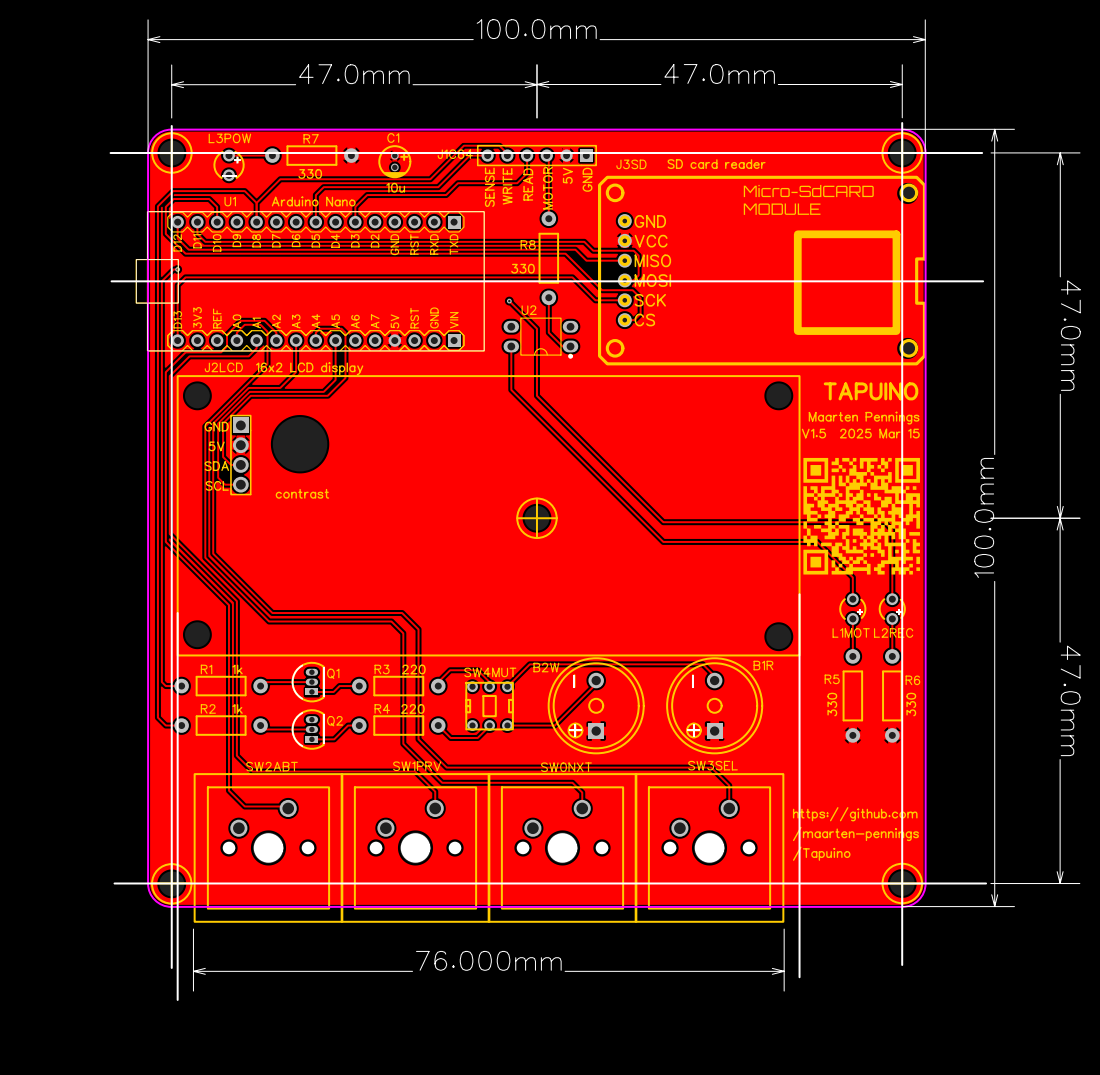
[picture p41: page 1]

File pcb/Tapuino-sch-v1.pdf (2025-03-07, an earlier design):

## LOAD and SAVE monitor

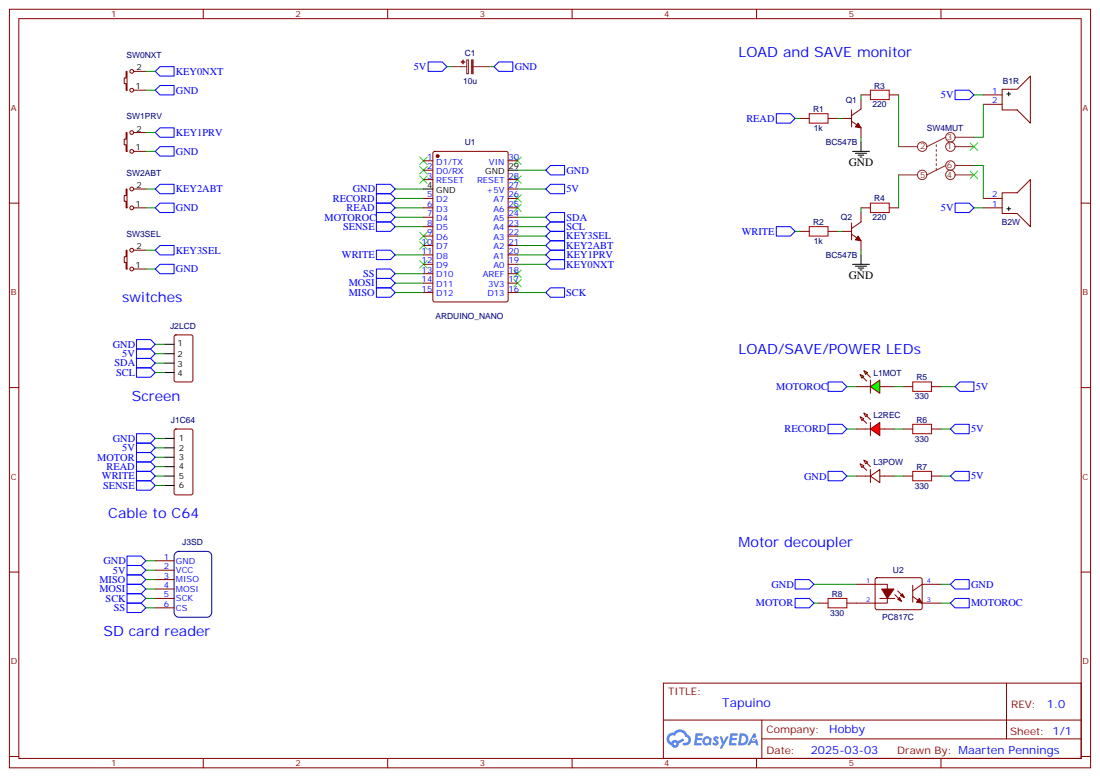
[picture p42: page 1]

LOAD/SAVE/POWER LEDs

Drawn By: Maarten Pennings

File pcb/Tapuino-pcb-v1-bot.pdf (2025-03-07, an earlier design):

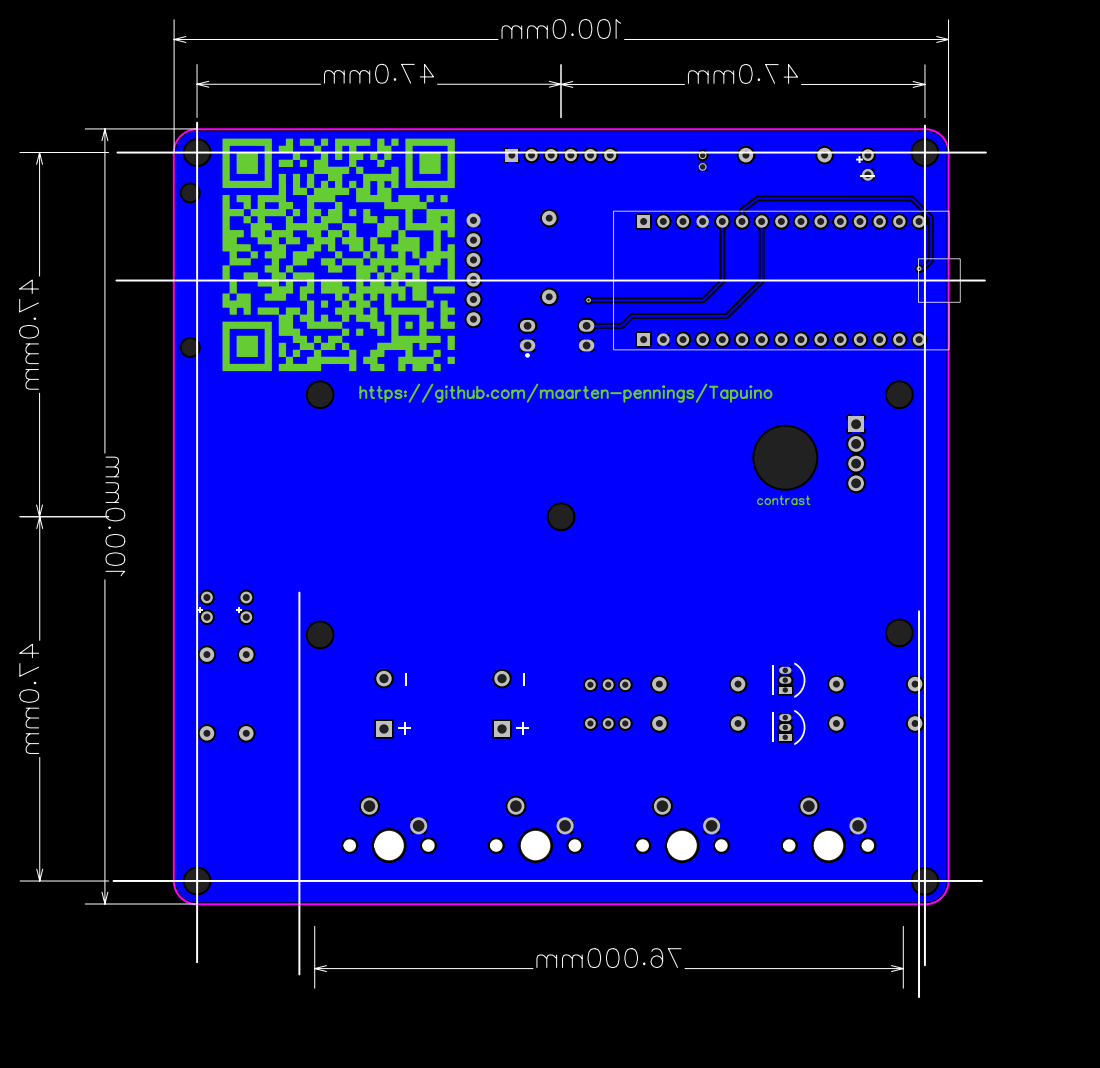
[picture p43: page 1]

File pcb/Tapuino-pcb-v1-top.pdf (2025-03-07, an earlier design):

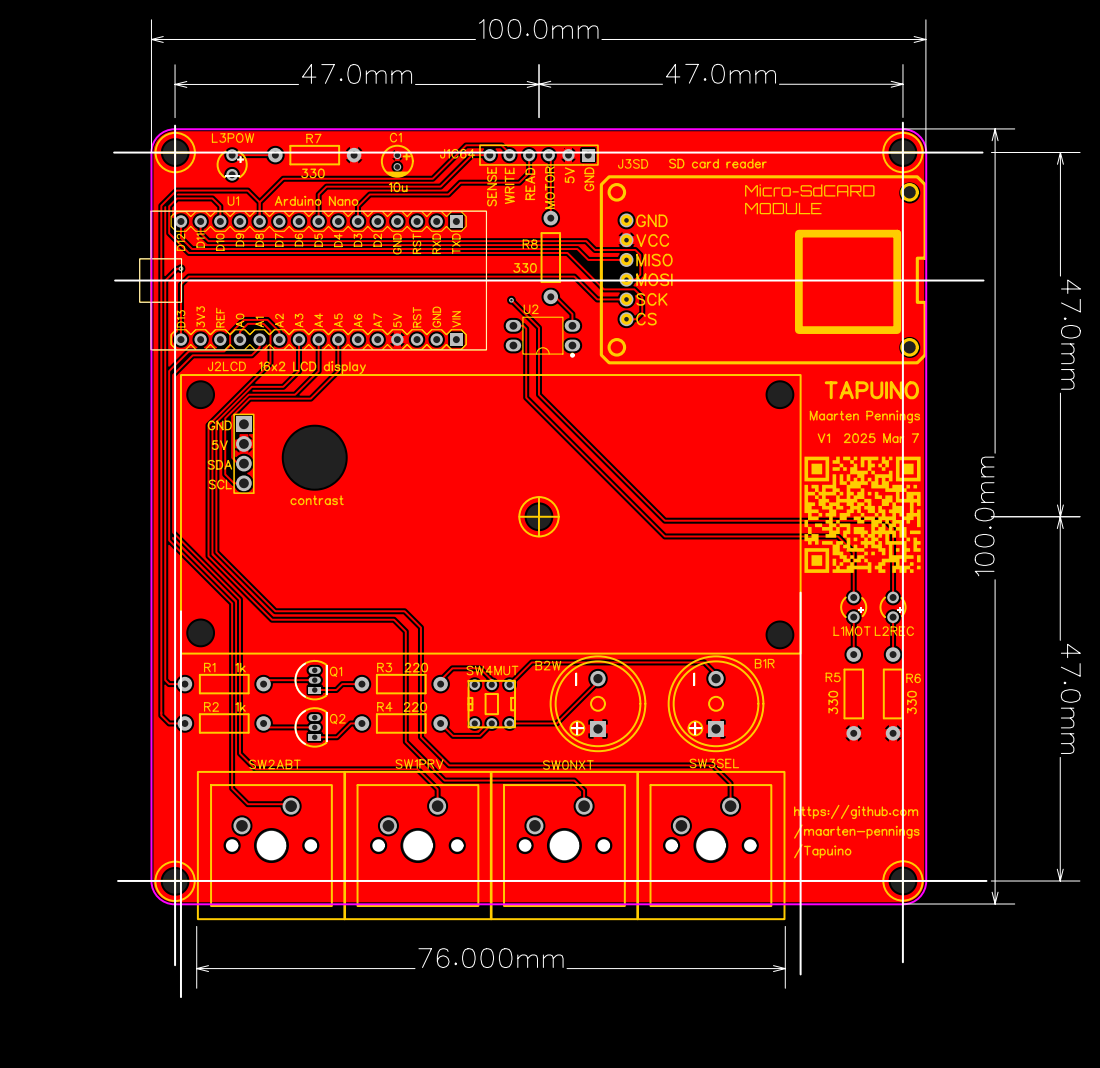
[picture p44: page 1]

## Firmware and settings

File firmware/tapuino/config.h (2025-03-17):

#ifndef _CONFIG_H
#define _CONFIG_H

#include "config-user.h"

// thanks stack overflow: http://stackoverflow.com/questions/4301471/c-macro-to-test-if-more-than-one-defined
#if defined(LCD_USE_SSD1306_OLED_MODULE) + defined(LCD_USE_1602_LCD_MODULE) + defined(LCD_USE_SSD131X_OLED_MODULE) != 1
  #error Either no or multiple LCD types defined! Have you created your config-user.h file?
#endif

#if defined(LCD_USE_SSD1306_OLED_MODULE)
  #if defined(LCD_SSD1306_128x64) + defined(LCD_SSD1306_128x32) != 1
    #error When using the SSD1306 module, define EITHER: LCD_SSD1306_128x64 or LCD_SSD1306_128x32 depending on your module type
  #endif
#endif

#if defined(TAPUINO_LANGUAGE_EN) + defined(TAPUINO_LANGUAGE_ES) + defined(TAPUINO_LANGUAGE_IT) + defined(TAPUINO_LANGUAGE_TR) + defined(TAPUINO_LANGUAGE_DE) != 1
  #error Either no or multiple languages defined! Have you created your config-user.h file?
#endif


#define LCD_BIT_RS          0    // Register select
#define LCD_BIT_RW          1    // Read / Write
#define LCD_BIT_EN          2    // Enable
#define LCD_BIT_BACKLIGHT   3    // Backlight
#define LCD_BIT_DATA0       4    // 4 bit data, bit 0
#define LCD_BIT_DATA1       5    // 4 bit data, bit 1
#define LCD_BIT_DATA2       6    // 4 bit data, bit 2
#define LCD_BIT_DATA3       7    // 4 bit data, bit 3
// LCD dimensions config
#define LCD_NUM_LINES       2    // number of display lines on the LCD
#define MAX_LCD_LINE_LEN    16   // max number of characters on a line

// Timing constant defaults, these will only apply until eeprom values are saved
#define TICKER_RATE         250  // milliseconds, granularity 10ms
#define TICKER_HOLD         1250 // milliseconds, ticker begin and end hold time, granularity 10ms
#define KEY_REPEAT_START    500  // milliseconds, granularity 10ms
#define KEY_REPEAT_NEXT     300  // milliseconds, granularity 10ms
#define REC_FINALIZE_TIME   2000 // milliseconds, granularity 10ms

// TWI for pullups
#define TWI_PORT            PORTC
#define TWI_PIN_SDA         4
#define TWI_PIN_SCL         5

// port definitions, change for different wiring
#define TAPE_READ_PORT      PORTD
#define TAPE_READ_DDR       DDRD
#define TAPE_READ_PIN       3
#define TAPE_READ_PINS      PIND
#define TAPE_READ_LOW()     TAPE_READ_PORT &= ~_BV(TAPE_READ_PIN)
#define TAPE_READ_HIGH()    TAPE_READ_PORT |=  _BV(TAPE_READ_PIN)

#define TAPE_WRITE_PORT     PORTB
#define TAPE_WRITE_DDR      DDRB
#define TAPE_WRITE_PINS     PINB
#define TAPE_WRITE_PIN      0

/* The Sense pin on the original Datassette is a physical switch that only grounds the line when pressed, it's left
 * floating when no keys are pressed. This means that the pin should be driven in an open-collector fashion, otherwise
 * it can create problems, in particular on the Plus/4 where the Sense line is shared with data pin 2 of the User Port.
 *
 * This could be compensated in hardware (put a diode in series, cathode to Arduino side) or in software, by taking
 * advantage of the way ATmega pins are configured, which is what we do here:
 * - To set sense "high" we set the pin to input mode, pin will go Hi-Z and basically float
 * - To set it low, we switch to output mode which will implicitly be low (PORTD defaults to 0 and we never touch it)
 */
#define SENSE_PORT          PORTD
#define SENSE_DDR           DDRD
#define SENSE_PIN           5
#define SENSE_ON()          SENSE_DDR |= _BV(SENSE_PIN)
#define SENSE_OFF()         SENSE_DDR &= ~_BV(SENSE_PIN)

#define MOTOR_PORT          PORTD
#define MOTOR_DDR           DDRD
#define MOTOR_PIN           4
#define MOTOR_PINS          PIND
#define MOTOR_IS_OFF()      (MOTOR_PINS & _BV(MOTOR_PIN))

#define CONTROL_PORT        PORTD
#define CONTROL_DDR         DDRD
#define CONTROL_PIN0        6
#define CONTROL_PIN1        7
#define CONTROL_SET_BUS0()  CONTROL_PORT &= ~(_BV(CONTROL_PIN0) | _BV(CONTROL_PIN1))
#define CONTROL_SET_BUS1()  { CONTROL_PORT &= ~_BV(CONTROL_PIN1); CONTROL_PORT |= _BV(CONTROL_PIN0); }

#define REC_LED_PORT        PORTD
#define REC_LED_DDR         DDRD
#define REC_LED_PIN         2
#define REC_LED_OFF()       REC_LED_PORT |= _BV(REC_LED_PIN)
#define REC_LED_ON()        REC_LED_PORT &= ~_BV(REC_LED_PIN)

// comment this line if you are using HW1.0
#define KEYS_INPUT_PULLUP
#define KEYS_READ_PORT      PORTC
#define KEYS_READ_DDR       DDRC
#define KEYS_READ_PINS      PINC
#define KEY_SELECT_PIN      3
#define KEY_ABORT_PIN       2
#define KEY_PREV_PIN        1
#define KEY_NEXT_PIN        0

// debugging
//#define ENABLE_SERIAL

#endif

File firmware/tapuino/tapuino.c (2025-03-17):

#include <avr/io.h>
#include <util/delay.h>
#include <avr/interrupt.h>
#include <avr/eeprom.h>
#include <inttypes.h>
#include <string.h>
#include <stdio.h>
#include <stdlib.h>

#include "version.h"
#include "integer.h"
#include "config.h"

#include "spi.h"
#include "ff.h"
#include "mmc.h"
#include "diskio.h"
#include "serial.h"
#include "comms.h"
#include "lcd_interface.h"
#include "lcdutils.h"
#include "memstrings.h"
#include "fileutils.h"
#include "menu.h"


typedef enum
{
  C64,
  VIC,
  C16,
} MACHINE_TYPE;

typedef enum
{
  PAL,
  NSTC,
} VIDEO_MODE;


// magic strings found in the TAP header, represented as uint32_t values in little endian format (reversed string)
#define TAP_MAGIC_C64      0x2D343643   // "C64-"  as "-46C"
#define TAP_MAGIC_C16      0x2D363143   // "C16-"  as "-61C"
#define TAP_MAGIC_POSTFIX1 0x45504154   // "TAPE"  as "EPAT"
#define TAP_MAGIC_POSTFIX2 0x5741522D   // "-RAW"  as "WAR-"

struct TAP_INFO {
  uint8_t version;              // TAP file format version:
                                // Version  0: 8-bit data, 0x00 indicates overflow
                                //          1: 8-bit, 0x00 indicates 24-bit overflow to follow
                                //          2: same as 1 but with 2 half-wave values
  uint8_t platform;             // Platform 0: C64
                                //          1: VIC
                                //          2: C16
  uint8_t video;                // Video    0: PAL 
                                //          1: NTSC
  uint8_t reserved;
  volatile uint32_t length;     // total length of the TAP data excluding header in bytes
  volatile uint32_t cycles;     // 
};

static struct TAP_INFO g_tap_info;

// the maximum TAP delay is a 24-bit value i.e. 0xFFFFFF cycles
// we need this constant to determine if the loader has switched off the motor before the tap has completed
// which would cause the code to enter an endless loop (when the motor is off the buffers do not progress)
// so we check during the buffer wait loop to see if we have exceeded the maximum delay time and exit if so.
#define MAX_SIGNAL_CYCLES     (g_cycle_mult_raw * 0xFFFFFF * 2)

// helper variables for the ISR and loader code

static volatile uint8_t g_read_index;           // read index in the 256 byte buffer
static volatile uint8_t g_write_index;          // write index in the 256 byte buffer
static volatile uint8_t g_signal_2nd_half;      // dual use flag: flag to indicate that the 2nd half of the signal should be output, or that recording has started
static volatile uint32_t g_total_timer_count;   // number of (AVR) cycles that the timer has been running for
static volatile uint8_t g_tap_file_complete;    // flag to indicate that all bytes have been read from the TAP
static volatile uint32_t g_tap_file_pos;        // current read position in the TAP (bytes)
static uint32_t g_pulse_length = 0;             // length of pulse in uS
static uint32_t g_pulse_length_save;            // saved length for 2nd half of the signal
static volatile uint32_t g_overflow;            // write signal overflow timer detection
static volatile uint32_t g_timer_tick = 0;      // timer tick at 100Hz (10 ms interval)

uint8_t g_machine_type = C64;
uint8_t g_video_mode = PAL;
static double g_cycle_mult_raw = 0;             // multiplier to convert a 24 bit TAP value into uS
static double g_cycle_mult_8 = 0;               // multiplier to convert an 8 bit TAP value into uS

volatile uint8_t g_invert_signal = 0;           // invert the signal for transmission/reception to/from a real Datasette

// all rate values are stored as milliseconds / 10.
// the global ticker runs at 100Hz which then maps 1-1 with these values
// So e.g. the key read function in comms.c: input_callback() is called by the global 100Hz timer, in this function g_key_repeat_next is used to determine the time between key repeats.
// each time this value is decremented 10 ms have passed, so a value of 100 is 100*10 = 1000 ms or 1 second repeat.

volatile uint16_t g_ticker_rate = TICKER_RATE / 10;
volatile uint16_t g_ticker_hold_rate = TICKER_HOLD / 10;
// volatile uint16_t g_key_repeat_start = KEY_REPEAT_START / 10;
volatile uint16_t g_key_repeat_next = KEY_REPEAT_NEXT / 10;
volatile uint16_t g_rec_finalize_time = REC_FINALIZE_TIME / 10;

volatile uint8_t g_rec_auto_finalize = 1;

volatile uint8_t g_is_paused = 0;

void setup_cycle_timing() {
  double ntsc_cycles_per_second;
  double pal_cycles_per_second;

  switch (g_machine_type)
  {
    default:
    case C64:
      ntsc_cycles_per_second = 1022272;
      pal_cycles_per_second  = 985248;
    break;
    case VIC:
      ntsc_cycles_per_second = 1022727;
      pal_cycles_per_second  = 1108404;
    break;
    case C16:
      ntsc_cycles_per_second = 894886;
      pal_cycles_per_second  = 886724;
    break;
  }
  
  switch(g_video_mode)
  {
    case PAL:
      g_cycle_mult_raw = (1000000.0 / pal_cycles_per_second);
    break;
    case NSTC:
      g_cycle_mult_raw = (1000000.0 / ntsc_cycles_per_second);
    break;
  }
  g_cycle_mult_8   = (g_cycle_mult_raw * 8.0);
}

uint32_t get_timer_tick() {
  return g_timer_tick;
}

// on rising edge of signal from C64
ISR(TIMER1_CAPT_vect) {
  uint32_t tap_data;

  if(g_signal_2nd_half) {                             // finished measuring 
    g_pulse_length = ICR1;                            // pulse length = ICR1 i.e. timer count
    g_pulse_length += (g_overflow << 16);             // add overflows
    g_pulse_length >>= 4;                             // turn raw tick values at 1/16th us into 1us i.e. divide by 16
    // start counting here
    g_overflow = 0;
    TCNT1 = 0;
    tap_data = g_pulse_length / g_cycle_mult_8;         // get the standard divided value
    
    if (tap_data == 0) {                              // safe guard
      tap_data++;
    }
    if (tap_data < 256) {                             // short signal
      g_fat_buffer[g_read_index++] = (uint8_t) tap_data;
      g_tap_file_pos++;
    } else {                                          // long signal
      tap_data = g_pulse_length / g_cycle_mult_raw;     // get the raw divided value (cycles)
      g_fat_buffer[g_read_index++] = 0;
      g_fat_buffer[g_read_index++] = (uint8_t) (tap_data & 0xff);
      g_fat_buffer[g_read_index++] = (uint8_t) ((tap_data & 0xff00) >> 8);
      g_fat_buffer[g_read_index++] = (uint8_t) ((tap_data & 0xff0000) >> 16);
      g_tap_file_pos += 4;
    }
  } else {
    // if this is the first time in, zero the count, otherwise the count starts at the high edge of the signal in the code above
    g_signal_2nd_half = 1;
    g_overflow = 0;
    TCNT1 = 0;
  }
  
}

ISR(TIMER1_OVF_vect){
  if (!MOTOR_IS_OFF()) {
    g_overflow++;
  }
}
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

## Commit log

2025-03-07 pcb and case
    [sleeve-square.stl]
2025-03-10 added switch link
2025-03-16 added assembly
2025-03-17 added with correct dir name
    [config.h, diskio.h]
2025-04-06 Second print
    [Inlay2.stl, ShellTop2.stl]
2025-04-26 case v3
    [Inlay3.stl, ShellTop3.stl]
2025-04-26 2nd assembly
